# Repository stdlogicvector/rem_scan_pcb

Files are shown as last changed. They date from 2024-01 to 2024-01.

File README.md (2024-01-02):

# rem_scan_pcb

## An open source scan controller for SEMs

- Firmware: https://github.com/stdlogicvector/rem_scan
- GUI: https://github.com/stdlogicvector/rem_scan_gui

This PCB features two 16bit DACs to steer the electron beam of an SEM and two 16bit ADCs to acquire the image signal from up to two detectors.

It can be controlled via USB. The FTDI chip provides a virtual comport, a fast FIFO connection and a JTAG port for flashing the gateware.
Currently, only the serial port is supported in the gateware and the GUI.

Additionally, a VGA monitor can be connected for a live view of the image.
On PCBv1, only the internal blockram is used. This limits the resolution to 100x75 pixels. The image is upscaled to 800x600.

PCBv2 has external RAM and allows a native resolution of 800x600.

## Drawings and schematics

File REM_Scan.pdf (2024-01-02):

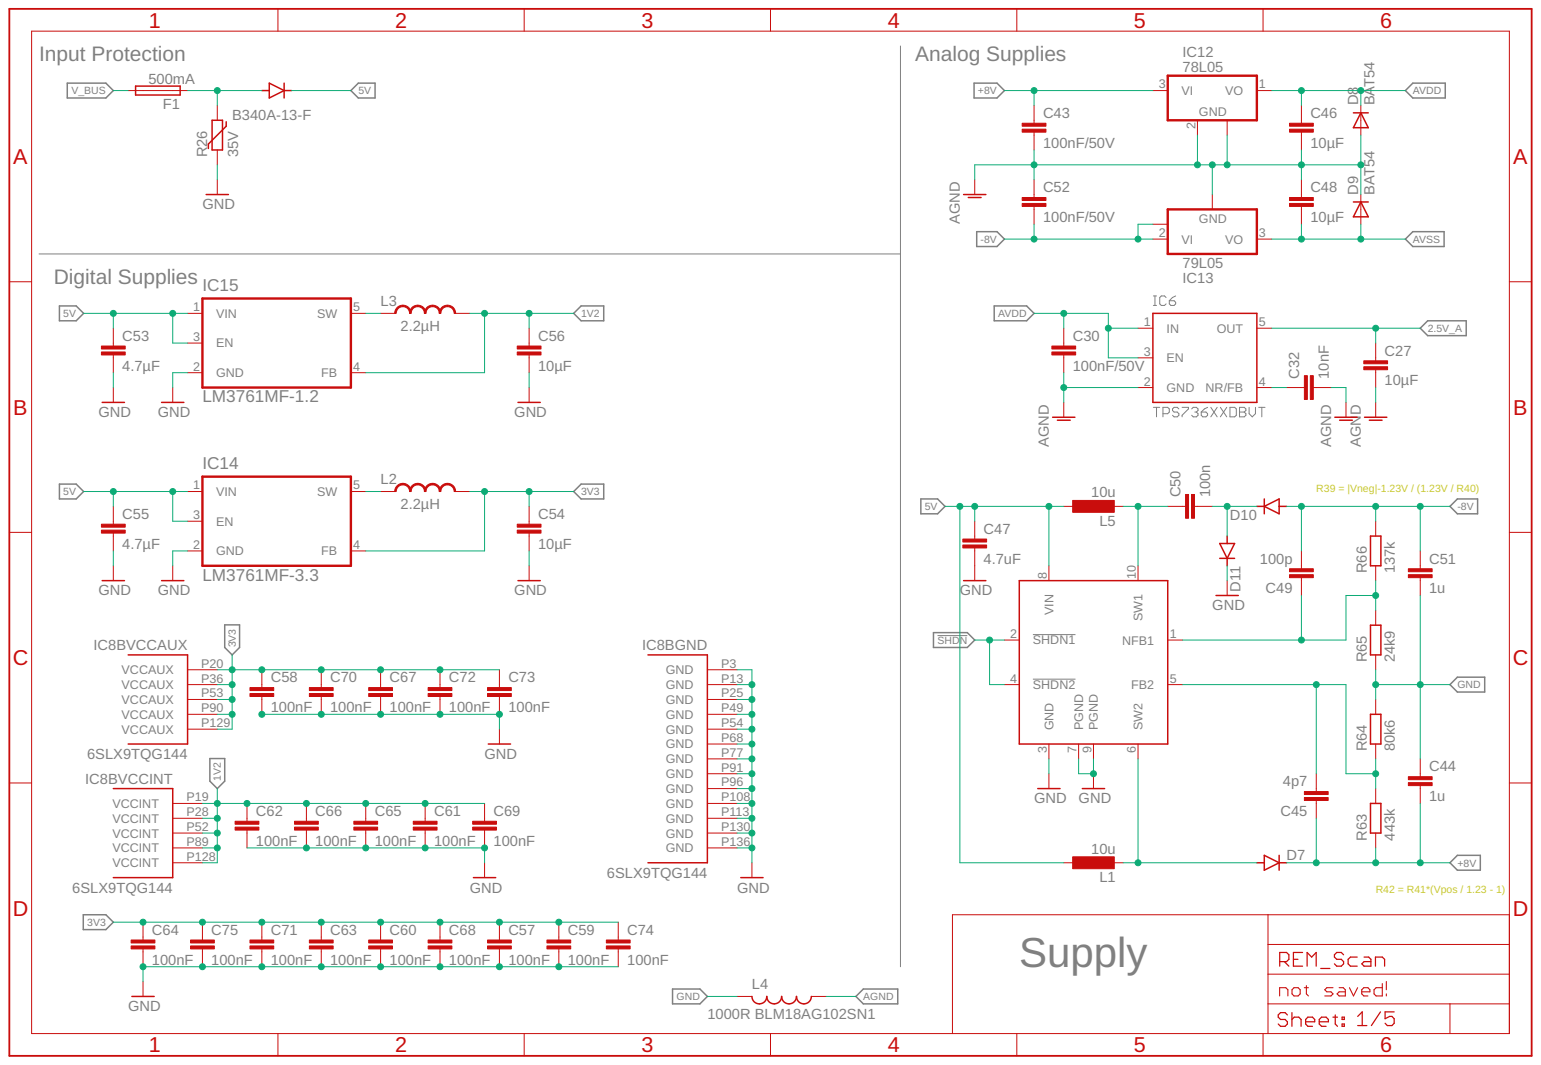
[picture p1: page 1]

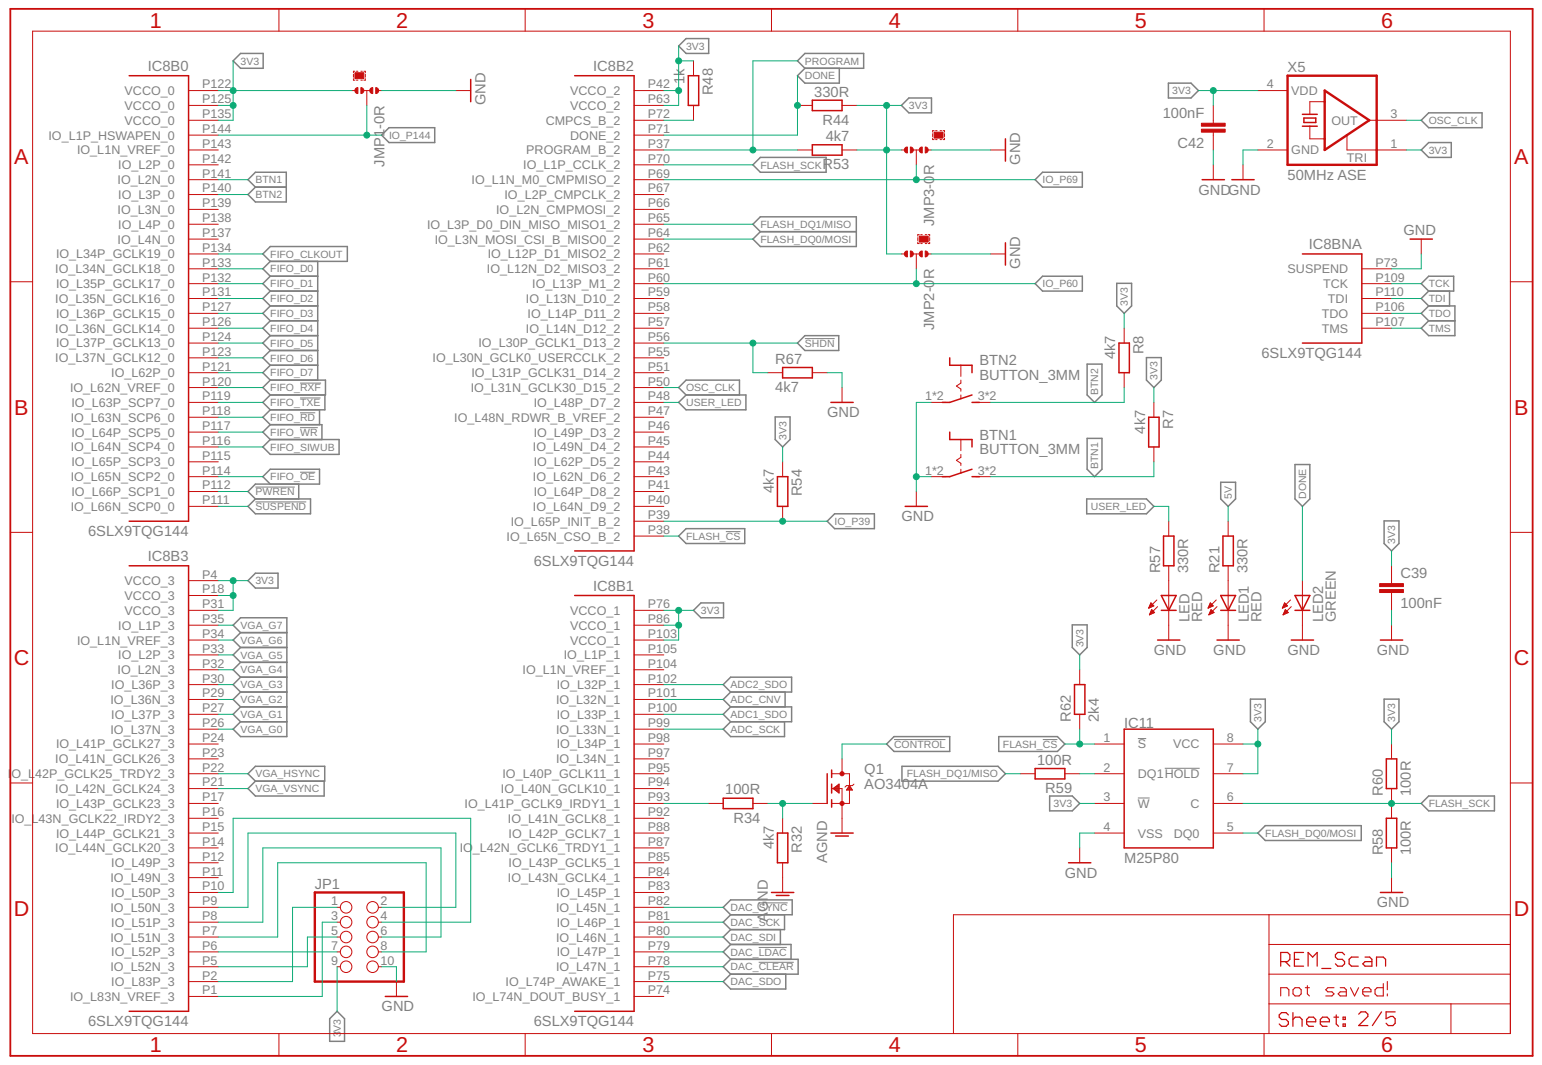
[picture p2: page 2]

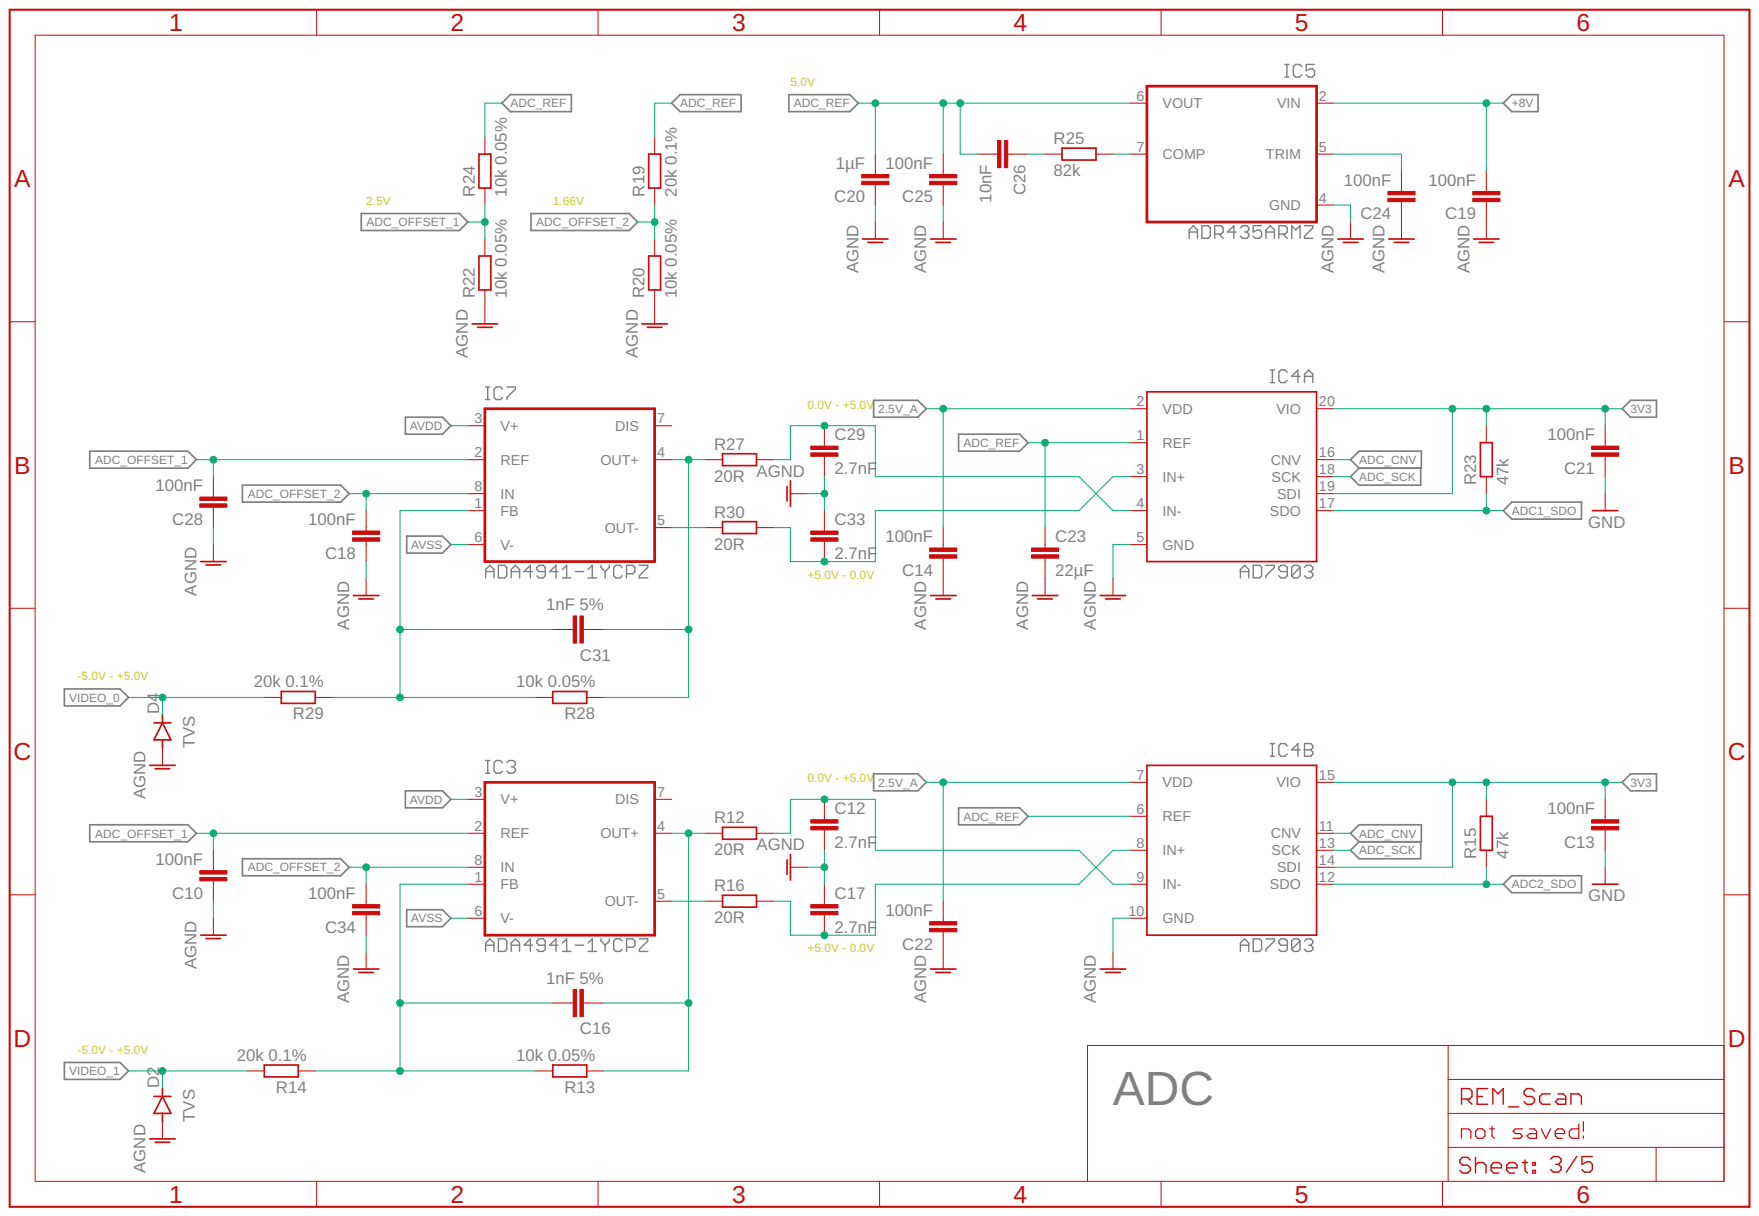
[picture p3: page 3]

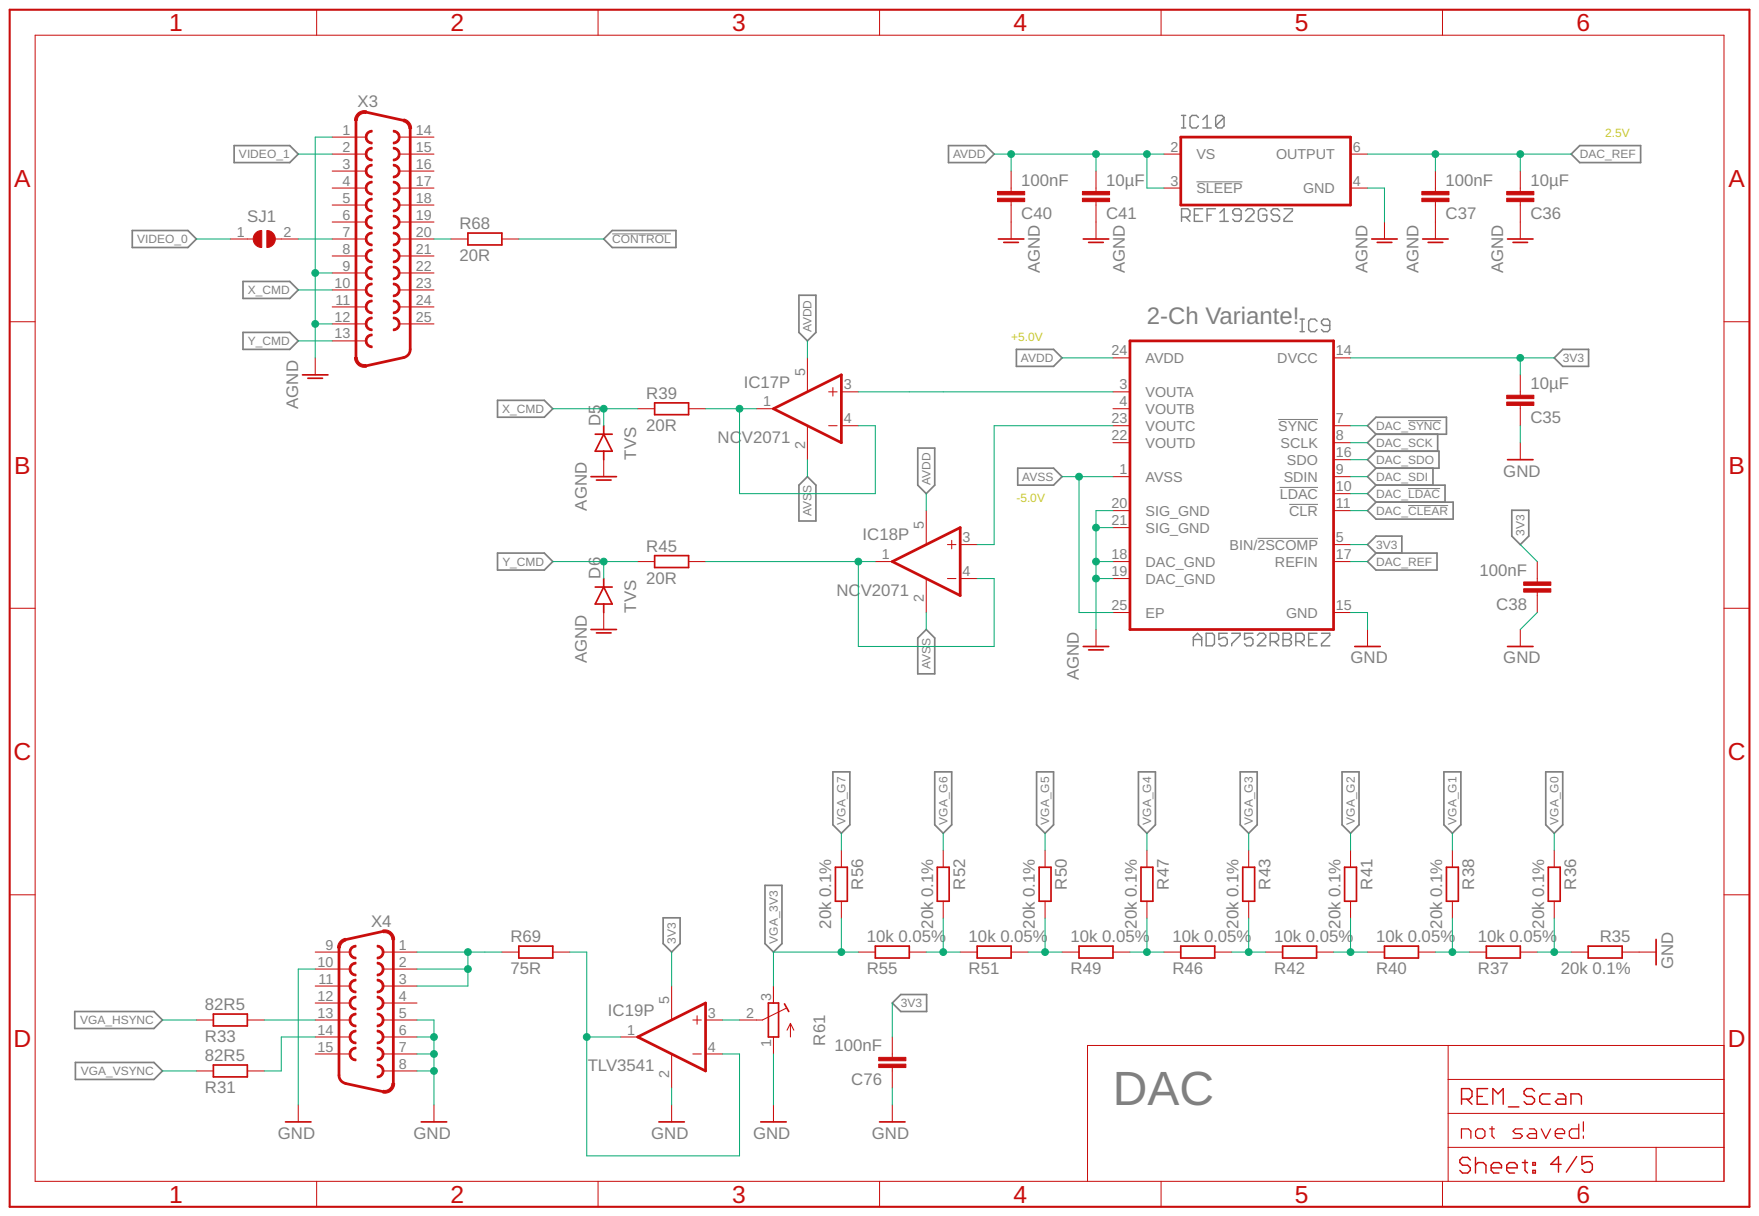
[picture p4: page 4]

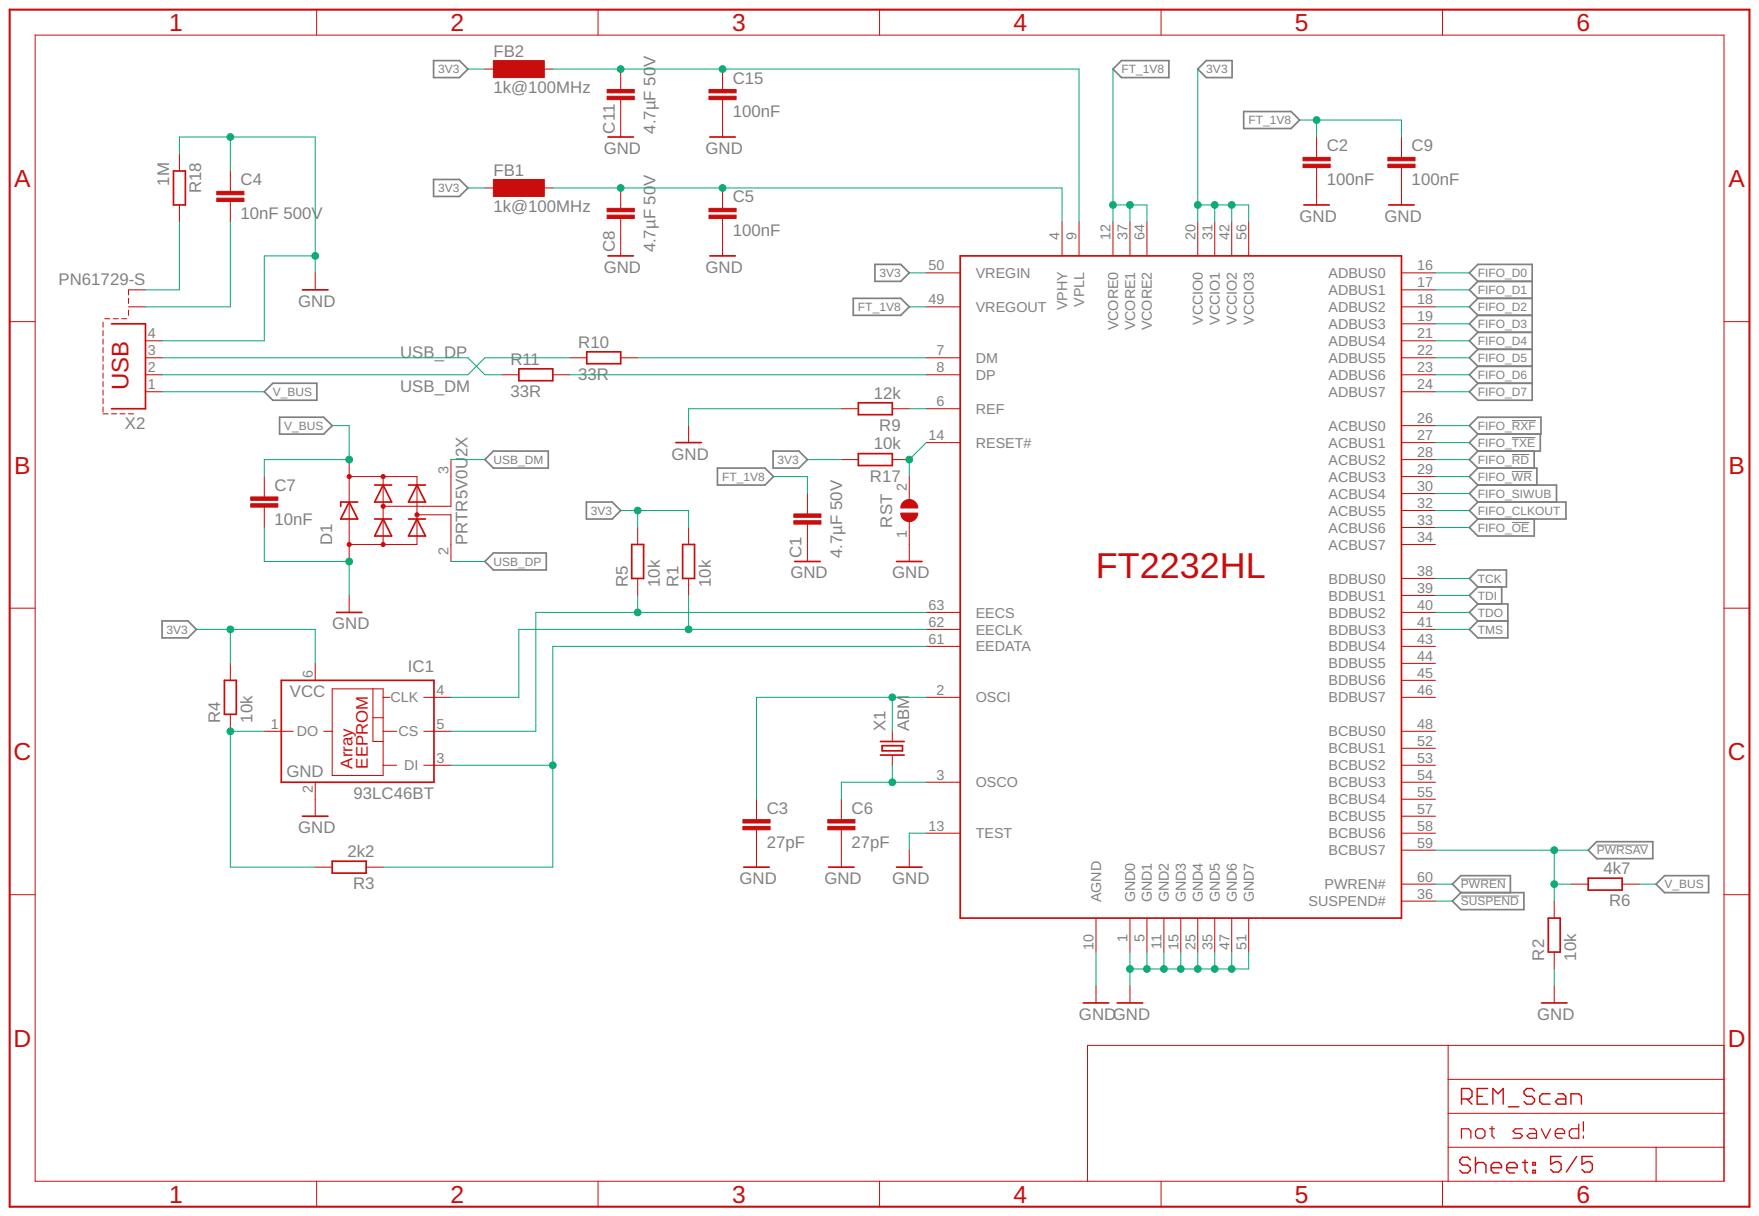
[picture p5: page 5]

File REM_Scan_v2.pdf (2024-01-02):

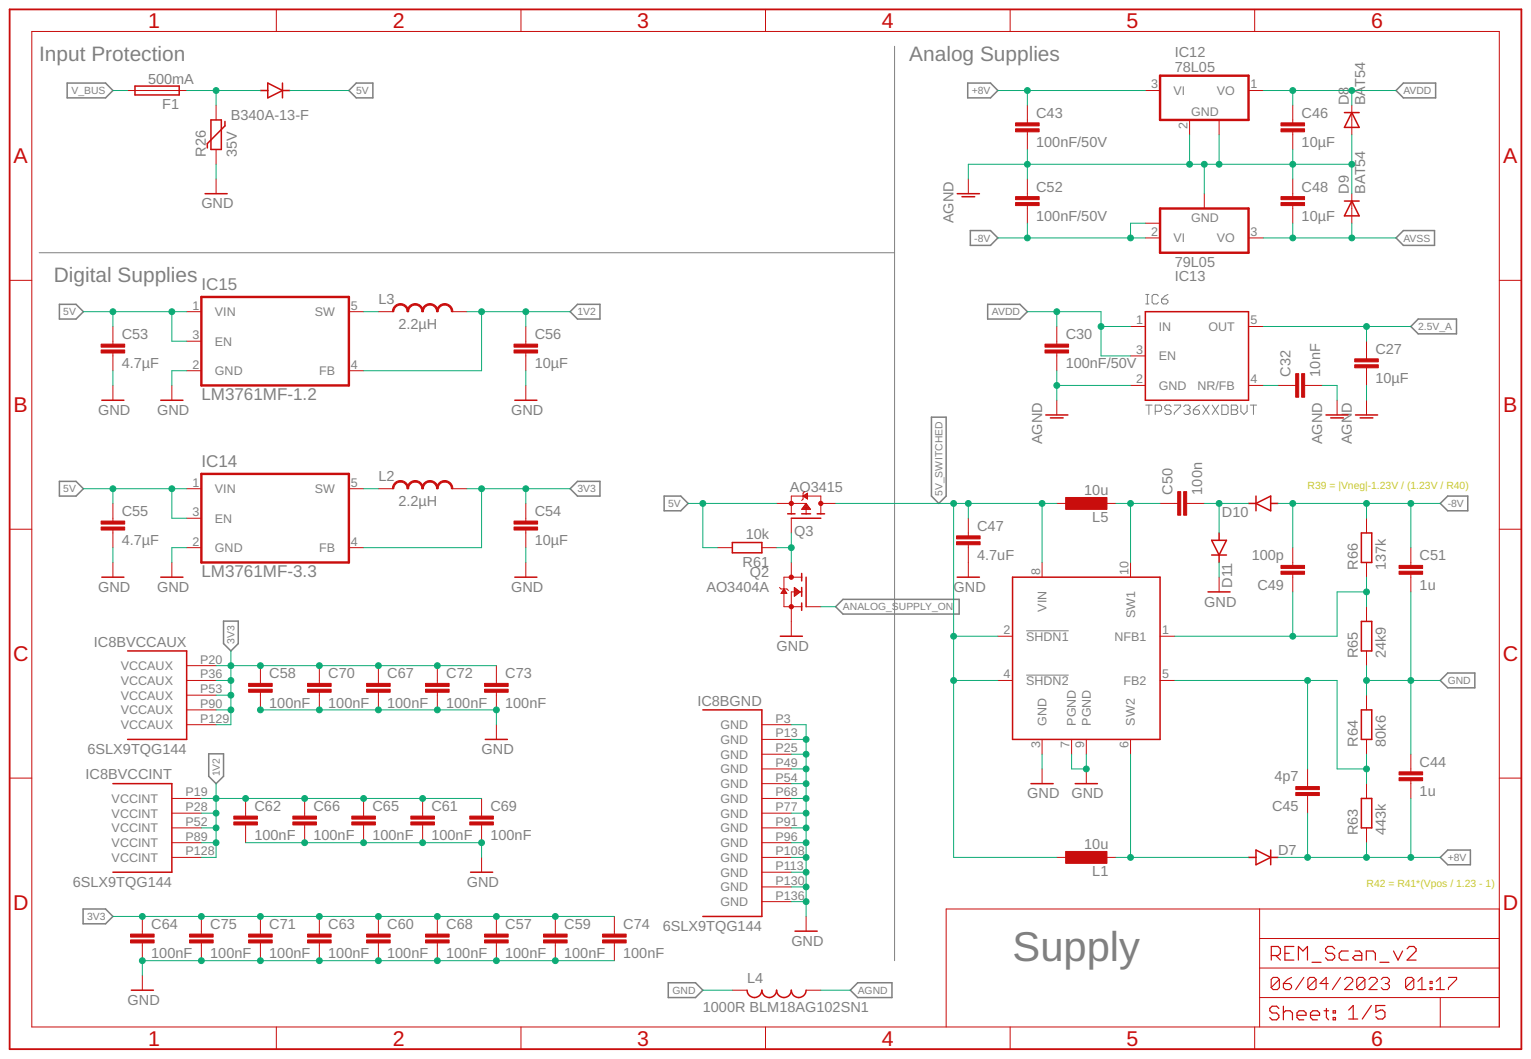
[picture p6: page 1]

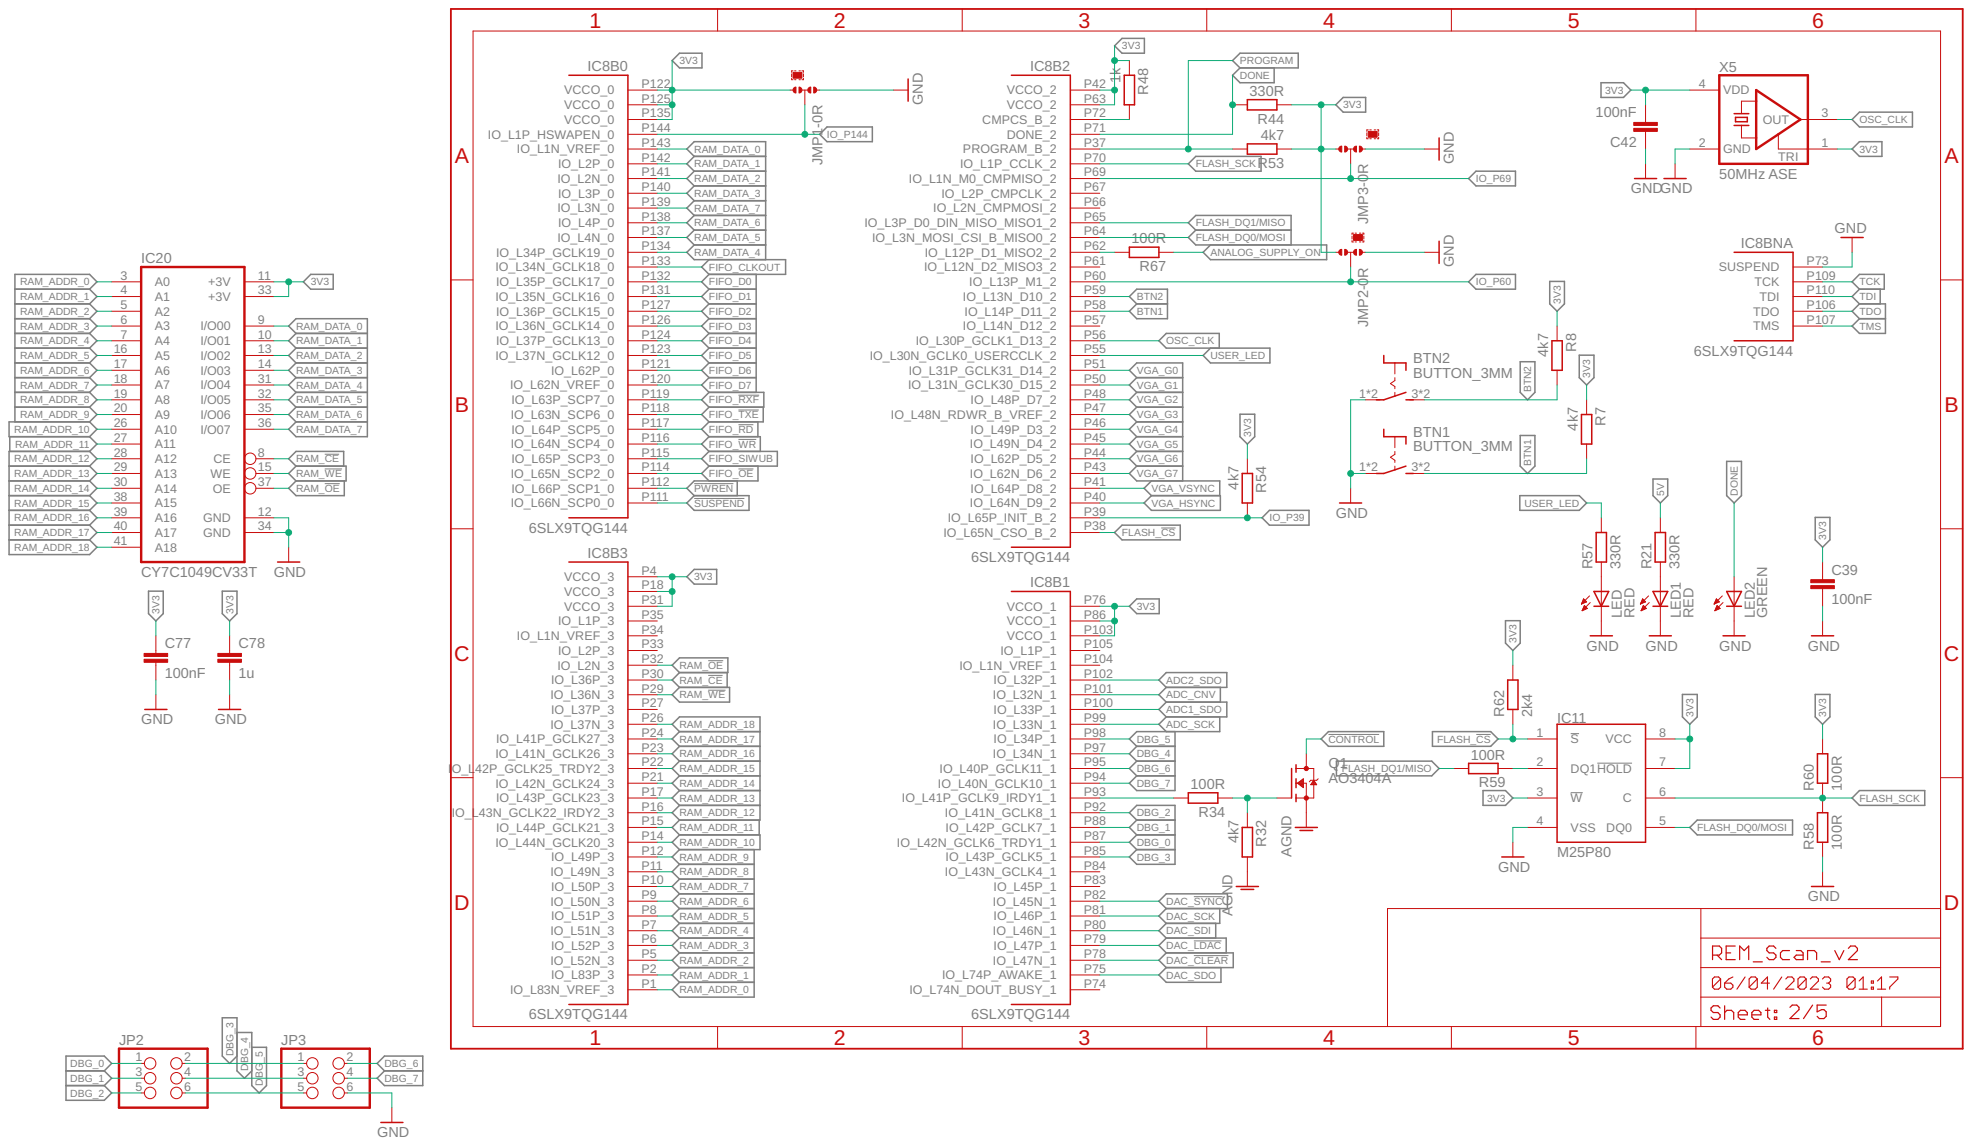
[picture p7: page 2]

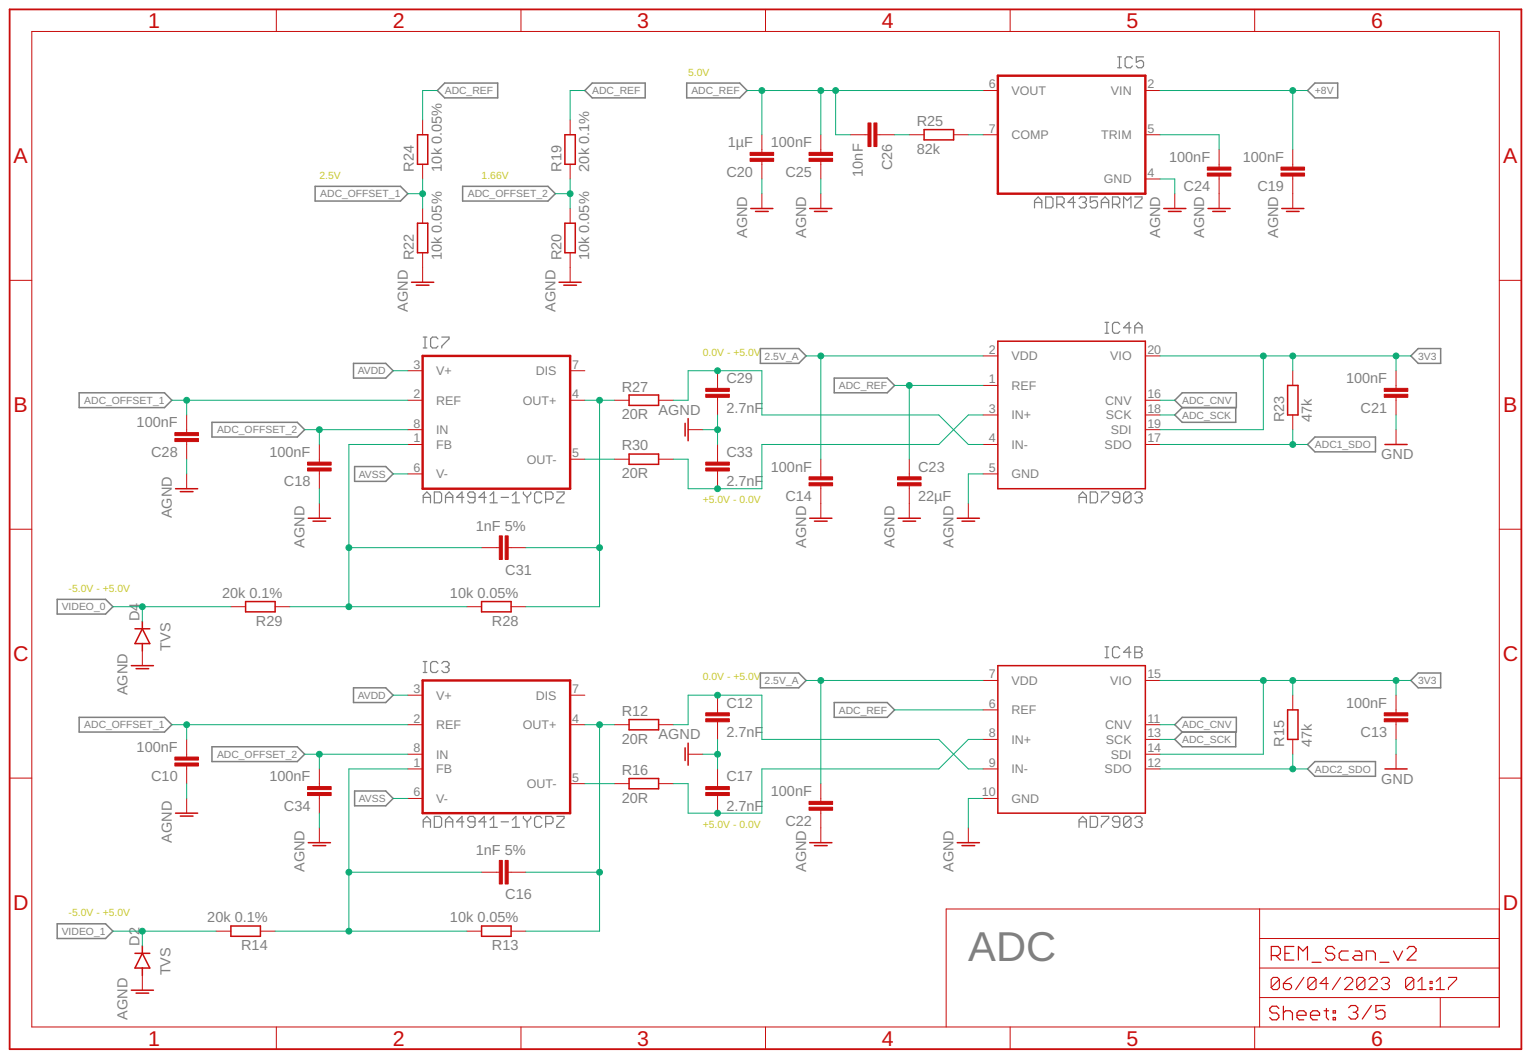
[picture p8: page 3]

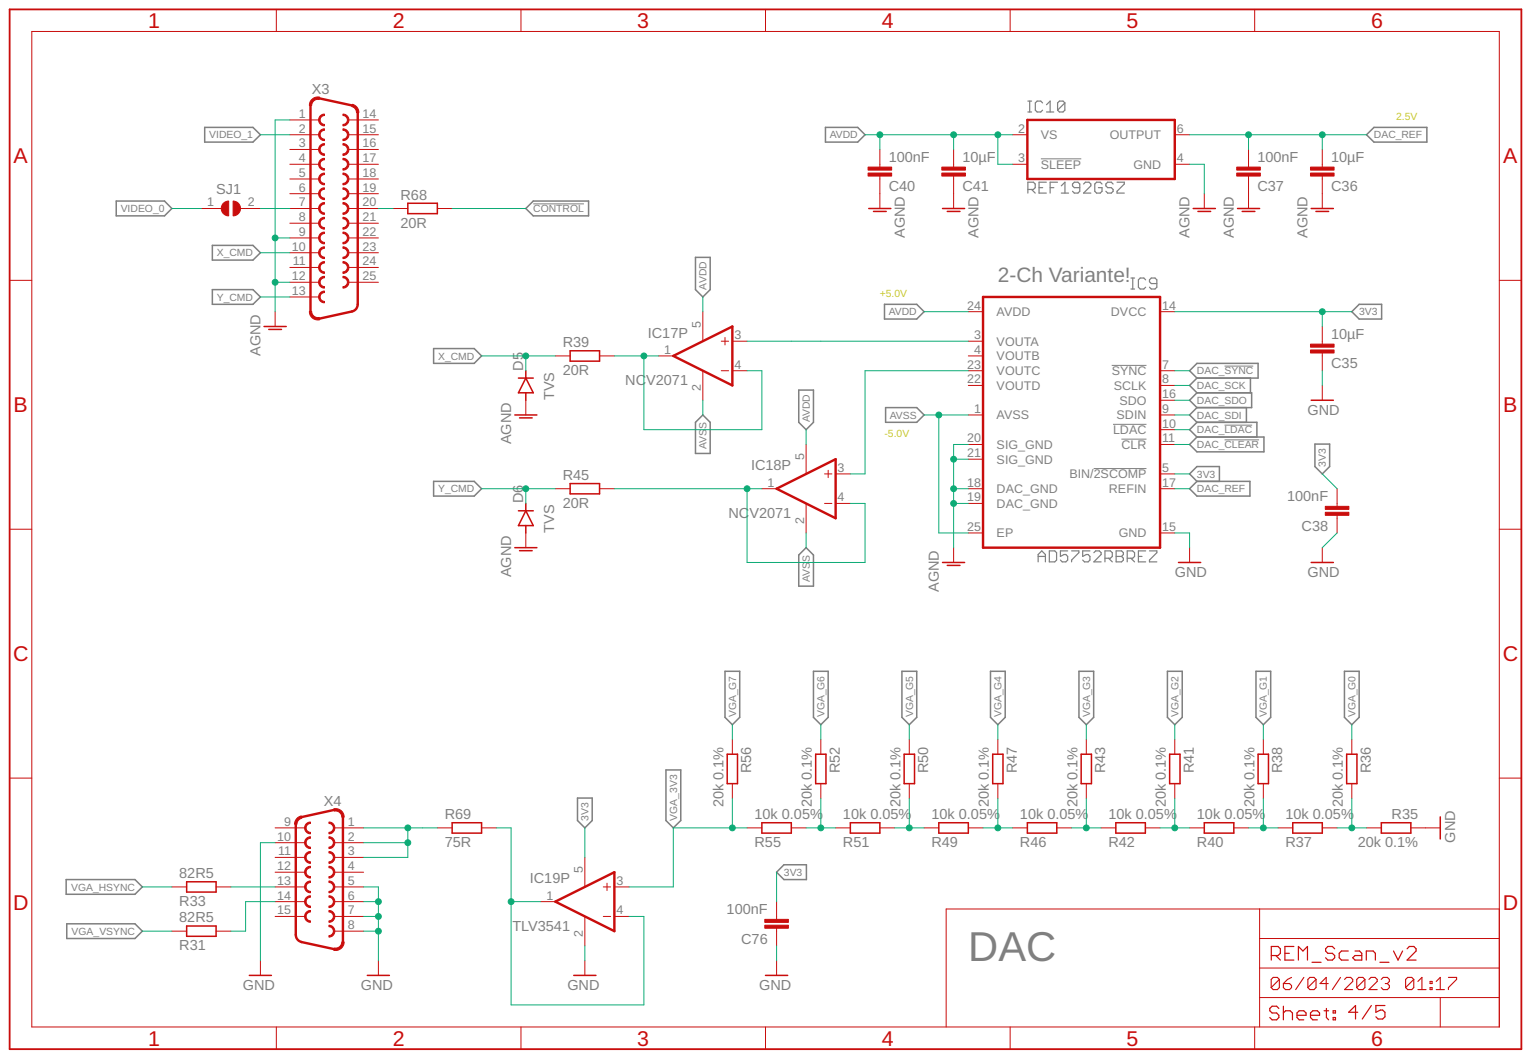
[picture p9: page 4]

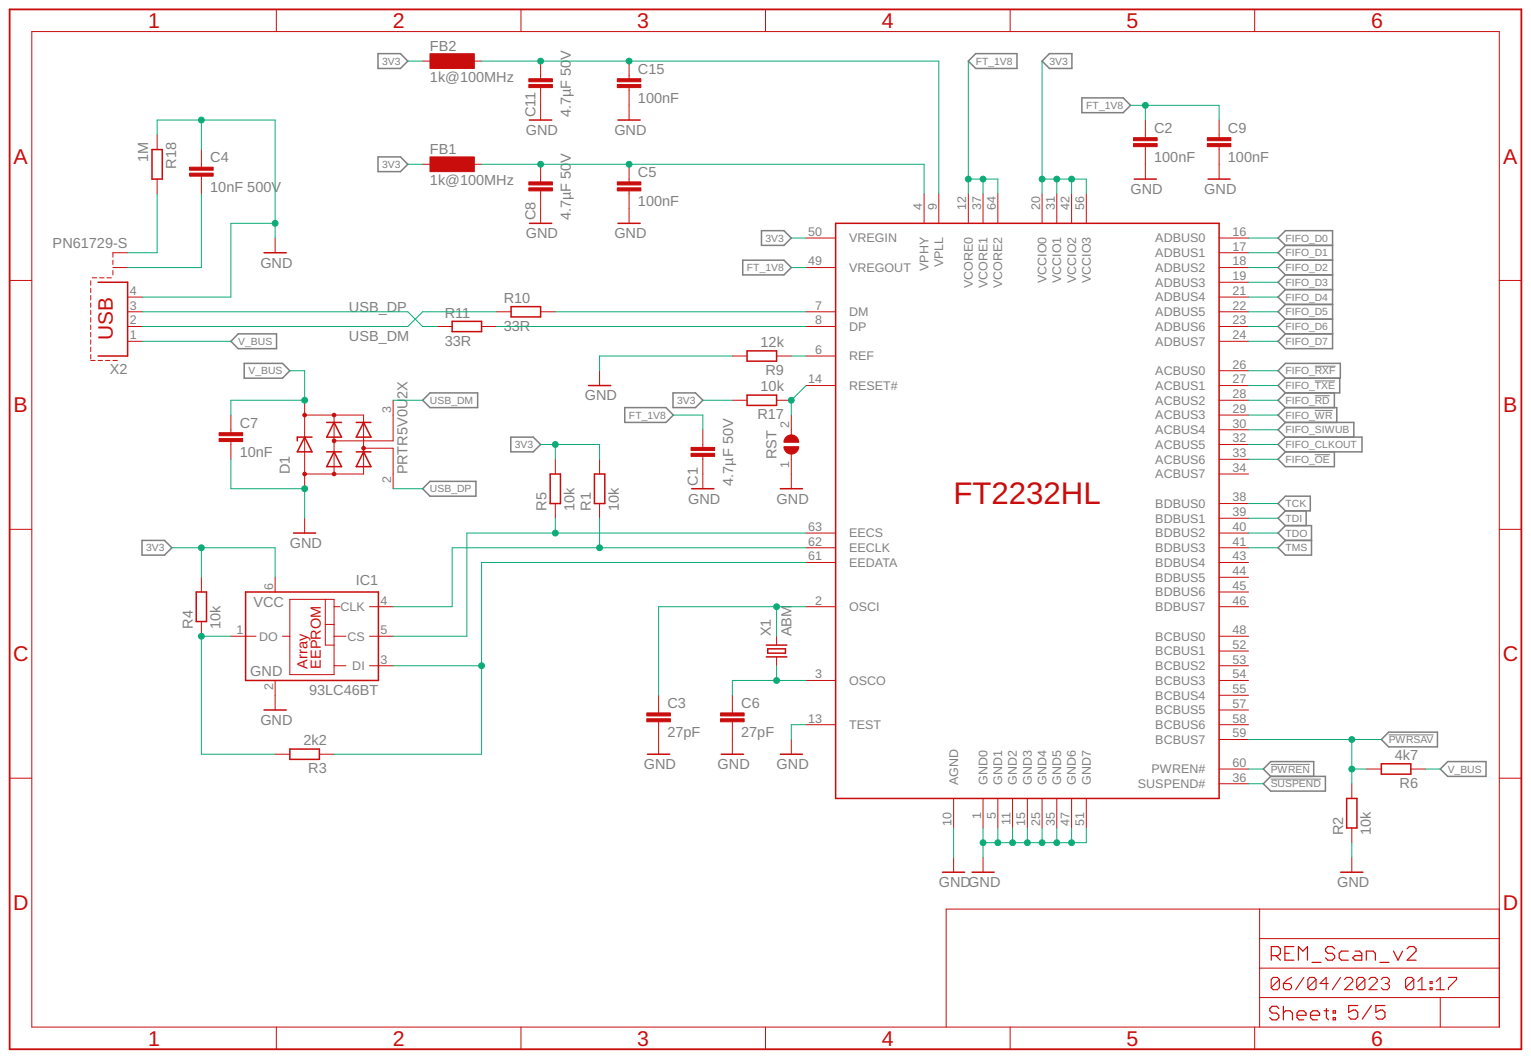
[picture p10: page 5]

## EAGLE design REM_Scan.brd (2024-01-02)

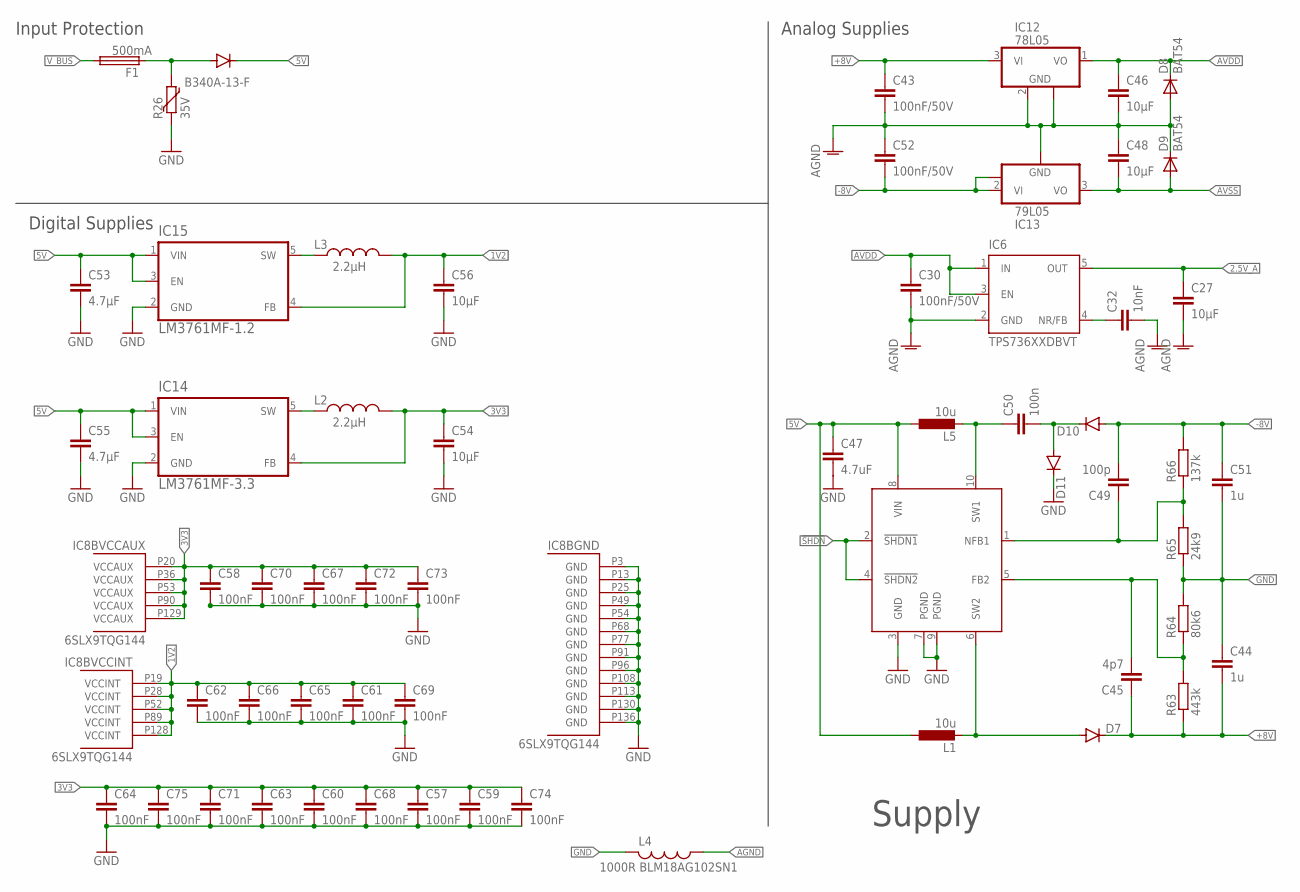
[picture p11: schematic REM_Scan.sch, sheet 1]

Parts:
C27, C46, C48: 10µF; C0603; FARNELL 2497051
C30, C43, C52: 100nF/50V; C0603
C32: 10nF; C0603
C44, C51: 1u; C1206; DIGIKEY 587-5596-1-ND
C45: 4p7; C0603
C47: 4.7uF; C3225
C49: 100p; C0603
C50: 100n; C0603
C53, C55: 4.7µF; C0603
C54, C56: 10µF; C0603
C57, C58, C59, C60, C61, C62, C63, C64, C65, C66, C67, C68, C69, C70, C71, C72, C73, C74, C75: 100nF; C0603
D3: B340A-13-F; DO214AA; FARNELL 1843668
D7, D10, D11: DIODE-SOD323-W; SOD323-W; DIGIKEY 1514-CMDSH05-4TRPBFREECT-ND
D8, D9: BAT54; SOD323-W; FARNELL 1459033
F1: 500mA; 1812; DIGIKEY F8132CT-ND
IC6: TPS736XXDBVT; SOT23-DBV
IC8: 6SLX9TQG144; TQ144; DIGIKEY 122-1747-ND
IC12: 78L05; SOT89; FARNELL 1366573
IC13: 79L05; SOT89; FARNELL 1467770
IC14: LM3761MF-3.3; SOT95P284X122-5N; FARNELL 1685767
IC15: LM3761MF-1.2; SOT95P284X122-5N; FARNELL 1685653
IC16: LT1945; MSOP10; DIGIKEY 505-LT1945EMS#PBF-ND
L1, L5: 10u; L3225P; DIGIKEY 445-174925-1-ND
L2, L3: 2.2µH; SO3314; FARNELL 2457514
L4: 1000R BLM18AG102SN1; L2012C; FARNELL 1515671
R26: 35V; R1206; DIGIKEY 118-ZV25K1206201NIR1CT-ND
R63: 443k; R0603
R64: 80k6; R0603
R65: 24k9; R0603
R66: 137k; R0603

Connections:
1V2: C56.1, C61.1, C62.1, C65.1, C66.1, C69.1, IC8.P19 (VCCINT), IC8.P28 (VCCINT), IC8.P52 (VCCINT), IC8.P89 (VCCINT), IC8.P128 (VCCINT), IC15.4 (FB), L3.2
2.5V_A: C27.1, IC6.5 (OUT); also elsewhere on the board
3V3: C54.1, C57.1, C58.1, C59.1, C60.1, C63.1, C64.1, C67.1, C68.1, C70.1, C71.1, C72.1, C73.1, C74.1, C75.1, IC8.P20 (VCCAUX), IC8.P36 (VCCAUX), IC8.P53 (VCCAUX), IC8.P90 (VCCAUX), IC8.P129 (VCCAUX), IC14.4 (FB), L2.2; also elsewhere on the board
5V: C47.1, C53.1, C55.1, D3.C, IC14.1 (VIN), IC14.3 (EN), IC15.1 (VIN), IC15.3 (EN), IC16.8 (VIN), L1.1, L5.1; also elsewhere on the board
!SHDN: IC16.2 (!SHDN1), IC16.4 (!SHDN2); also elsewhere on the board
+8V: C43.1, C44.2, C45.1, D7.C, IC12.3 (VI), R63.1; also elsewhere on the board
-8V: C49.2, C51.1, C52.2, D10.A, IC13.2 (VI), IC13.2@1 (VIN), R66.2
AGND: C27.2, C30.2, C32.2, C43.2, C46.2, C48.1, C52.1, D8.A, D9.C, IC6.2 (GND), IC12.2 (GND), IC12.2@1 (GND), IC13.1 (GND), L4.1; also elsewhere on the board
AVDD: C30.1, C46.1, D8.C, IC6.1 (IN), IC6.3 (EN), IC12.1 (VO); also elsewhere on the board
AVSS: C48.2, D9.A, IC13.3 (VO); also elsewhere on the board
GND: C44.1, C47.2, C51.2, C53.2, C54.2, C55.2, C56.2, C57.2, C58.2, C59.2, C60.2, C61.2, C62.2, C63.2, C64.2, C65.2, C66.2, C67.2, C68.2, C69.2, C70.2, C71.2, C72.2, C73.2, C74.2, C75.2, D11.C, IC8.P3 (GND), IC8.P13 (GND), IC8.P25 (GND), IC8.P49 (GND), IC8.P54 (GND), IC8.P68 (GND), IC8.P77 (GND), IC8.P91 (GND), IC8.P96 (GND), IC8.P108 (GND), IC8.P113 (GND), IC8.P130 (GND), IC8.P136 (GND), IC14.2 (GND), IC15.2 (GND), IC16.3 (GND), IC16.7 (PGND), IC16.9 (PGND), L4.2, R26.1, R64.2, R65.1; also elsewhere on the board
unnamed: IC15.5 (SW), L3.1
unnamed: C32.1, IC6.4 (NR/FB)
unnamed: C50.1, IC16.10 (SW1), L5.2
unnamed: C50.2, D10.C, D11.A
unnamed: D7.A, IC16.6 (SW2), L1.2
unnamed: C49.1, IC16.1 (NFB1), R65.2, R66.1
unnamed: C45.2, IC16.5 (FB2), R63.2, R64.1
unnamed: IC14.5 (SW), L2.1
SUPPLY_SEC: D3.A, F1.1, R26.2
V_BUS: F1.2; also elsewhere on the board

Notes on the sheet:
Input Protection
Supply
Digital Supplies
Analog Supplies

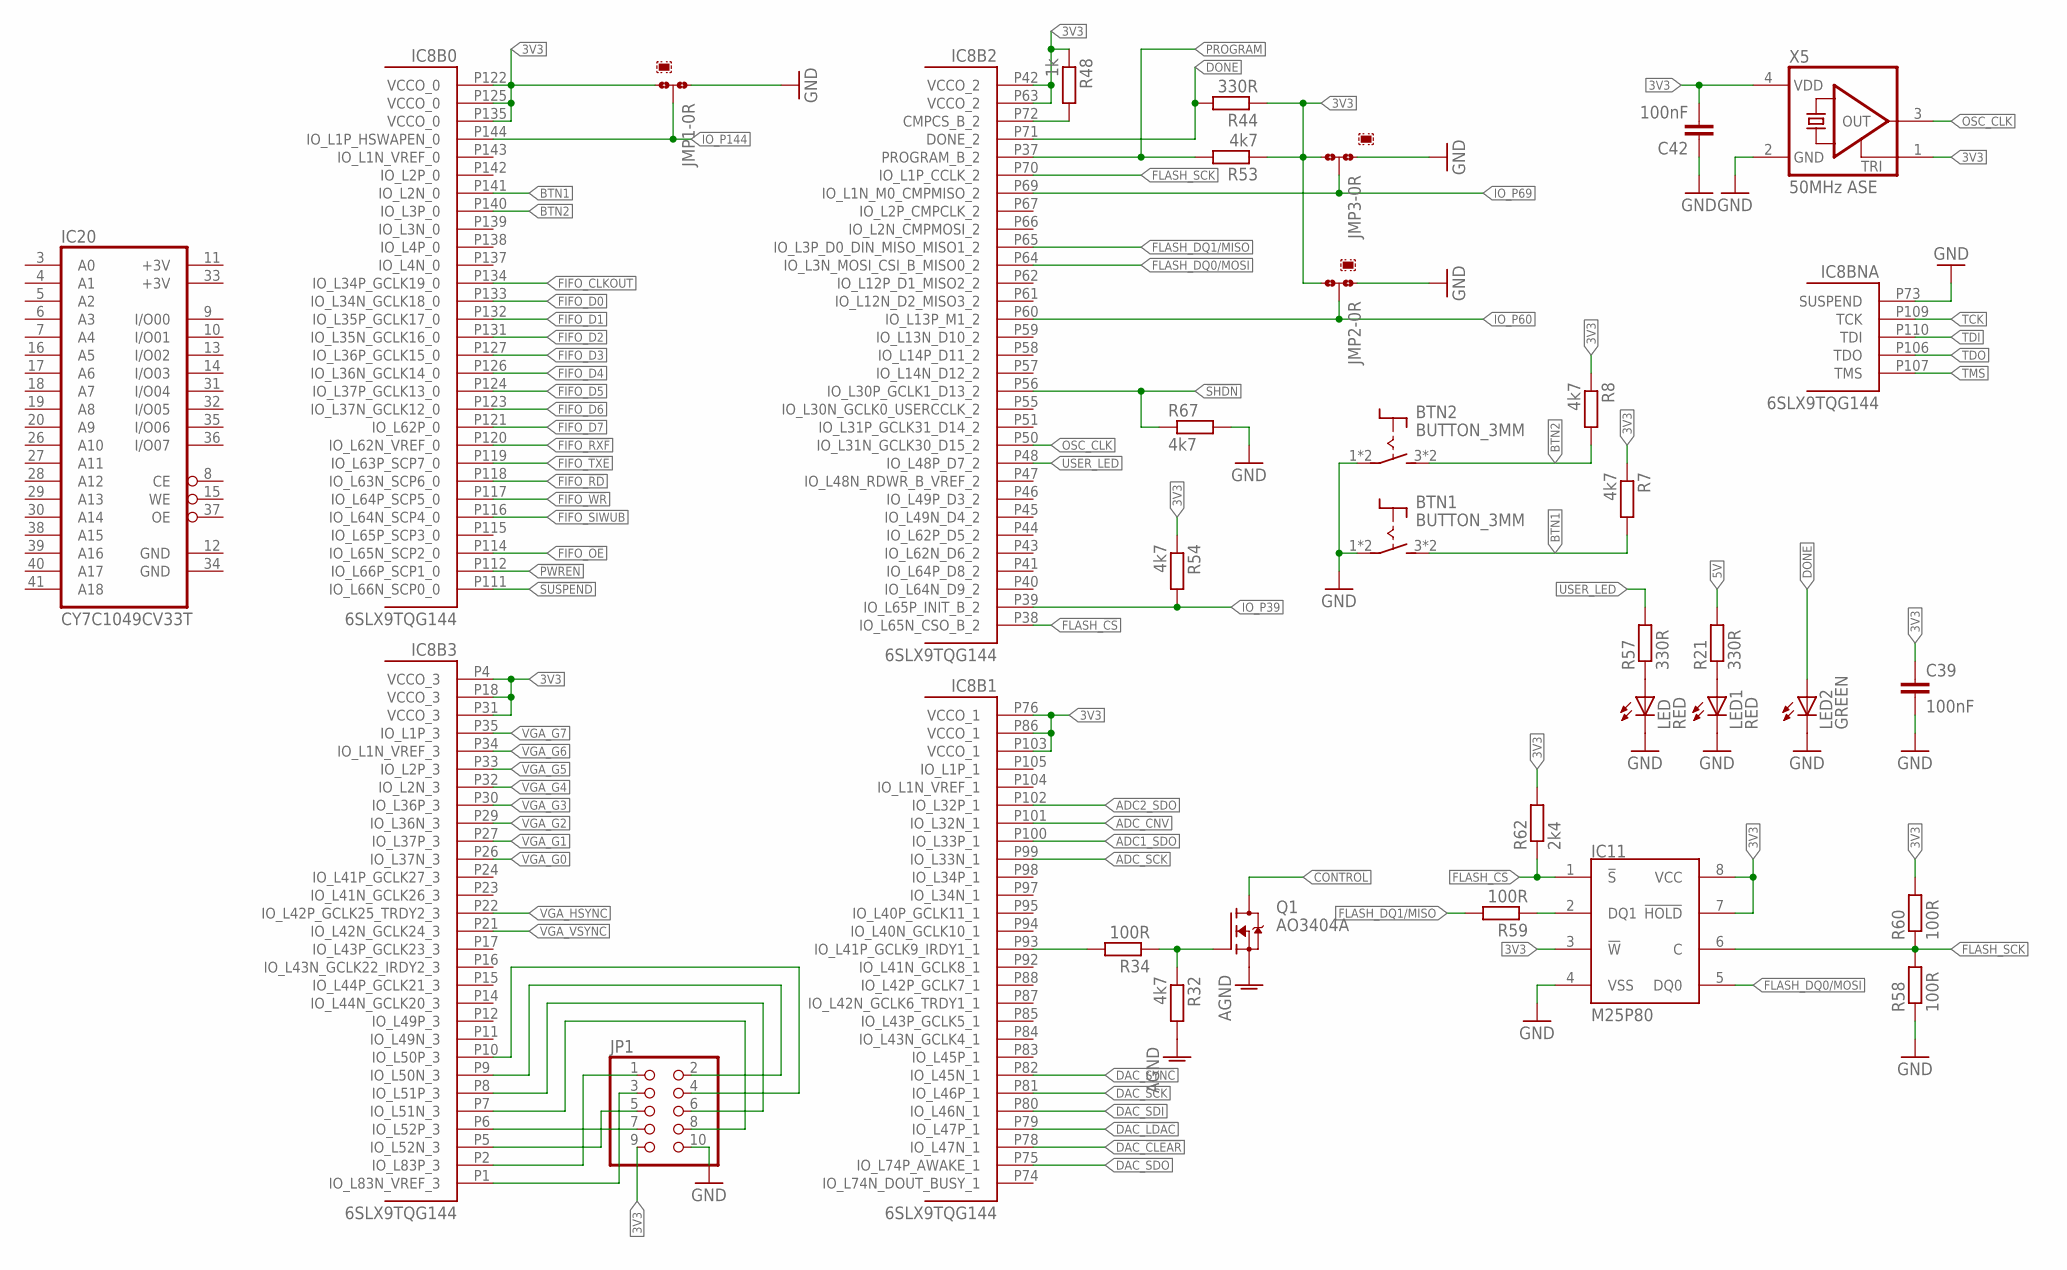
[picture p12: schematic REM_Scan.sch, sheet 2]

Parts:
BTN1, BTN2: BUTTON_3MM
C39, C42: 100nF; C0603
IC8: 6SLX9TQG144; TQ144; DIGIKEY 122-1747-ND
IC11: M25P80; SO-08
IC20: CY7C1049CV33T; TSOPII-Z44
JMP1, JMP2, JMP3: 1k; A0R-JMP
JP1: PINHD-2X5; 2X05
LED, LED1: RED; CHIP-LED0603; FARNELL 1685068
LED2: GREEN; CHIP-LED0603; FARNELL 1685068
Q1: AO3404A; SOT23; LCSC C30010
R7, R8, R32, R53, R54, R67: 4k7; R0603
R21, R44, R57: 330R; R0603
R34, R58, R59, R60: 100R; R0603
R48: 1k; R0603
R62: 2k4; R0603
X5: 50MHz ASE; ASE; DIGIKEY 535-9577-1-ND

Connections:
3V3: C39.1, C42.2, IC8.P4 (VCCO_3), IC8.P18 (VCCO_3), IC8.P31 (VCCO_3), IC8.P42 (VCCO_2), IC8.P63 (VCCO_2), IC8.P76 (VCCO_1), IC8.P86 (VCCO_1), IC8.P103 (VCCO_1), IC8.P122 (VCCO_0), IC8.P125 (VCCO_0), IC8.P135 (VCCO_0), IC11.3 (!W), IC11.7 (!HOLD), IC11.8 (VCC), JMP1.3, JMP2.3, JMP3.3, JP1.9, R7.1, R8.1, R44.1, R48.1, R53.1, R54.1, R60.2, R62.2, X5.1 (TRI), X5.4 (VDD); also elsewhere on the board
5V: R21.2; also elsewhere on the board
!CONTROL: Q1.3 (D); also elsewhere on the board
!PWREN: IC8.P112 (IO_L66P_SCP1_0); also elsewhere on the board
!SHDN: IC8.P56 (IO_L30P_GCLK1_D13_2), R67.1; also elsewhere on the board
!SUSPEND: IC8.P111 (IO_L66N_SCP0_0); also elsewhere on the board
+3V: IC20.11 (+3V), IC20.33 (+3V)
ADC1_SDO: IC8.P100 (IO_L33P_1); also elsewhere on the board
ADC2_SDO: IC8.P102 (IO_L32P_1); also elsewhere on the board
ADC_CNV: IC8.P101 (IO_L32N_1); also elsewhere on the board
ADC_SCK: IC8.P99 (IO_L33N_1); also elsewhere on the board
AGND: Q1.2 (S), R32.2; also elsewhere on the board
BTN1: BTN1.3 (S), BTN1.4 (S), IC8.P141 (IO_L2N_0), R7.2
BTN2: BTN2.3 (S), BTN2.4 (S), IC8.P140 (IO_L3P_0), R8.2
DAC_!CLEAR: IC8.P78 (IO_L47N_1); also elsewhere on the board
DAC_!LDAC: IC8.P79 (IO_L47P_1); also elsewhere on the board
DAC_!SYNC: IC8.P82 (IO_L45N_1); also elsewhere on the board
DAC_SCK: IC8.P81 (IO_L46P_1); also elsewhere on the board
DAC_SDI: IC8.P80 (IO_L46N_1); also elsewhere on the board
DAC_SDO: IC8.P75 (IO_L74P_AWAKE_1); also elsewhere on the board
DONE: IC8.P71 (DONE_2), LED2.A, R44.2
FIFO_!OE: IC8.P114 (IO_L65N_SCP2_0); also elsewhere on the board
FIFO_!RD: IC8.P118 (IO_L63N_SCP6_0); also elsewhere on the board
FIFO_!RXF: IC8.P120 (IO_L62N_VREF_0); also elsewhere on the board
FIFO_!TXE: IC8.P119 (IO_L63P_SCP7_0); also elsewhere on the board
FIFO_!WR: IC8.P117 (IO_L64P_SCP5_0); also elsewhere on the board
FIFO_CLKOUT: IC8.P134 (IO_L34P_GCLK19_0); also elsewhere on the board
FIFO_D0: IC8.P133 (IO_L34N_GCLK18_0); also elsewhere on the board
FIFO_D1: IC8.P132 (IO_L35P_GCLK17_0); also elsewhere on the board
FIFO_D2: IC8.P131 (IO_L35N_GCLK16_0); also elsewhere on the board
FIFO_D3: IC8.P127 (IO_L36P_GCLK15_0); also elsewhere on the board
FIFO_D4: IC8.P126 (IO_L36N_GCLK14_0); also elsewhere on the board
FIFO_D5: IC8.P124 (IO_L37P_GCLK13_0); also elsewhere on the board
FIFO_D6: IC8.P123 (IO_L37N_GCLK12_0); also elsewhere on the board
FIFO_D7: IC8.P121 (IO_L62P_0); also elsewhere on the board
FIFO_SIWUB: IC8.P116 (IO_L64N_SCP4_0); also elsewhere on the board
FLASH_!CS: IC8.P38 (IO_L65N_CSO_B_2), IC11.1 (!S), R62.1
FLASH_DQ0/MOSI: IC8.P64 (IO_L3N_MOSI_CSI_B_MISO0_2), IC11.5 (DQ0)
FLASH_DQ1/MISO: IC8.P65 (IO_L3P_D0_DIN_MISO_MISO1_2), R59.2
FLASH_SCK: IC8.P70 (IO_L1P_CCLK_2), IC11.6 (C), R58.2, R60.1
GND: BTN1.1, BTN1.2, BTN2.1, BTN2.2, C39.2, C42.1, IC8.P73 (SUSPEND), IC11.4 (VSS), IC20.12 (GND), IC20.34 (GND), JMP1.1, JMP2.1, JMP3.1, JP1.10, LED.C, LED1.C, LED2.C, R58.1, R67.2, X5.2 (GND); also elsewhere on the board
IO_P39: IC8.P39 (IO_L65P_INIT_B_2), R54.2
IO_P60: IC8.P60 (IO_L13P_M1_2), JMP2.2
IO_P69: IC8.P69 (IO_L1N_M0_CMPMISO_2), JMP3.2
IO_P144: IC8.P144 (IO_L1P_HSWAPEN_0), JMP1.2
unnamed: IC11.2 (DQ1), R59.1
unnamed: LED1.A, R21.1
unnamed: Q1.1 (G), R32.1, R34.1
unnamed: IC8.P72 (CMPCS_B_2), R48.2
unnamed: IC8.P93 (IO_L41P_GCLK9_IRDY1_1), R34.2
unnamed: LED.A, R57.1
unnamed: IC8.P6 (IO_L52P_3), JP1.7
unnamed: IC8.P7 (IO_L51N_3), JP1.8
unnamed: IC8.P5 (IO_L52N_3), JP1.5
unnamed: IC8.P8 (IO_L51P_3), JP1.6
unnamed: IC8.P1 (IO_L83N_VREF_3), JP1.3
unnamed: IC8.P2 (IO_L83P_3), JP1.1
unnamed: IC8.P9 (IO_L50N_3), JP1.2
unnamed: IC8.P10 (IO_L50P_3), JP1.4
OSC_CLK: IC8.P50 (IO_L31N_GCLK30_D15_2), X5.3 (OUT)
PROGRAM: IC8.P37 (PROGRAM_B_2), R53.2
TCK: IC8.P109 (TCK); also elsewhere on the board
TDI: IC8.P110 (TDI); also elsewhere on the board
TDO: IC8.P106 (TDO); also elsewhere on the board
TMS: IC8.P107 (TMS); also elsewhere on the board
USER_LED: IC8.P48 (IO_L48P_D7_2), R57.2
VGA_G0: IC8.P26 (IO_L37N_3); also elsewhere on the board
VGA_G1: IC8.P27 (IO_L37P_3); also elsewhere on the board
VGA_G2: IC8.P29 (IO_L36N_3); also elsewhere on the board
VGA_G3: IC8.P30 (IO_L36P_3); also elsewhere on the board
VGA_G4: IC8.P32 (IO_L2N_3); also elsewhere on the board
VGA_G5: IC8.P33 (IO_L2P_3); also elsewhere on the board
VGA_G6: IC8.P34 (IO_L1N_VREF_3); also elsewhere on the board
VGA_G7: IC8.P35 (IO_L1P_3); also elsewhere on the board
VGA_HSYNC: IC8.P22 (IO_L42P_GCLK25_TRDY2_3); also elsewhere on the board
VGA_VSYNC: IC8.P21 (IO_L42N_GCLK24_3); also elsewhere on the board

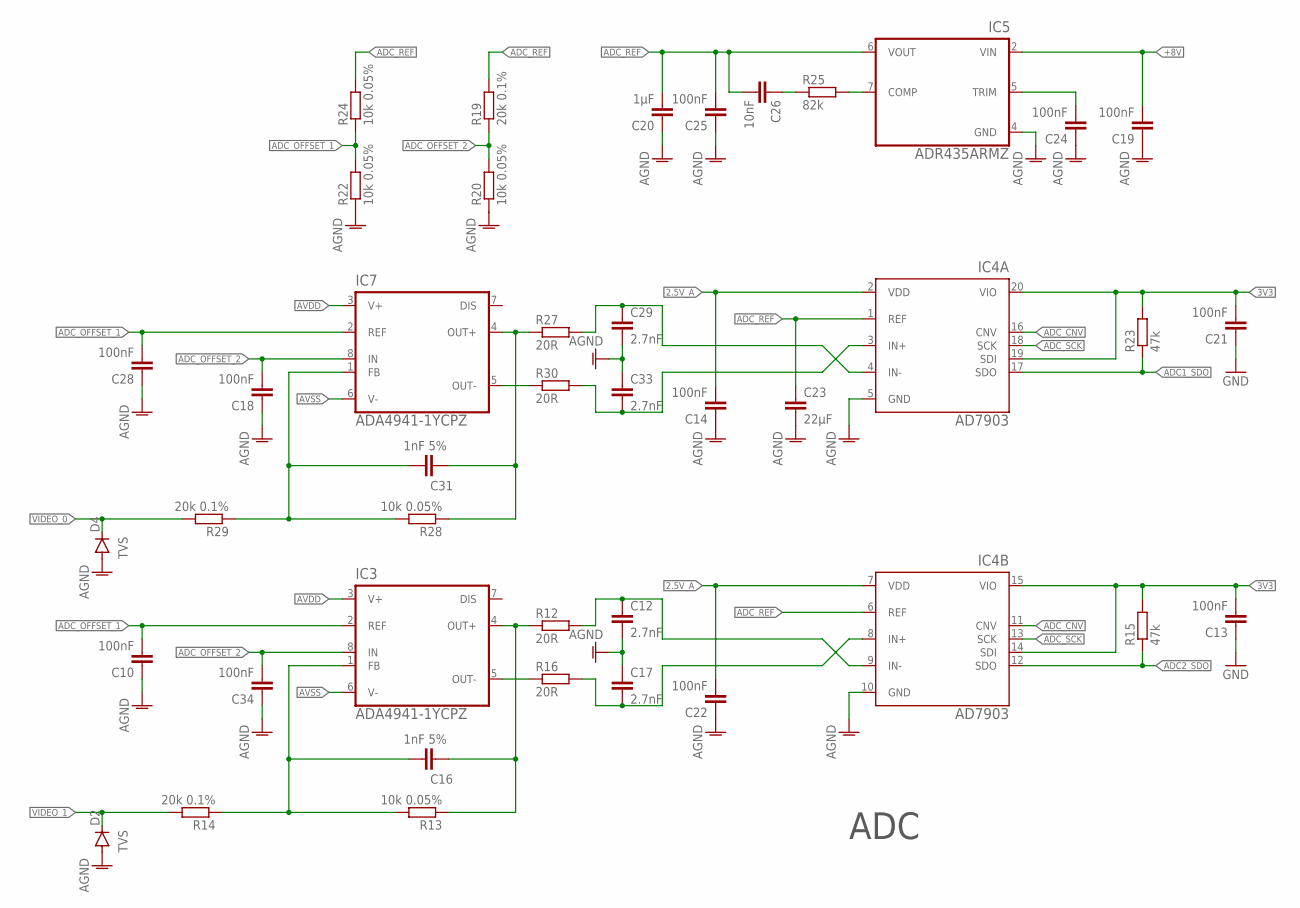
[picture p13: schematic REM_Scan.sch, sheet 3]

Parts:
C10, C13, C14, C18, C19, C21, C22, C24, C25, C28, C34: 100nF; C0603
C12, C17, C29, C33: 2.7nF; C0603K; FARNELL 1759094
C16, C31: 1nF 5%; C0603; FARNELL 1789718
C20: 1µF; C0603; FARNELL 2496835
C23: 22µF; C0805K; FARNELL 1845739
C26: 10nF; C0603
D2, D4: TVS; SOD123; DIGIKEY 641-1986-1-ND
IC3, IC7: ADA4941-1YCPZ; LFCSP_VD8_CP-8-2
IC4: AD7903; RQ-20
IC5: ADR435ARMZ; MSOP08
R12, R16, R27, R30: 20R; R0603; FARNELL 9330763
R13, R20, R22, R24, R28: 10k 0.05%; R0603; FARNELL 1688472
R14, R19, R29: 20k 0.1%; R0603; FARNELL 1717605
R15, R23: 47k; R0603; FARNELL 2141566
R25: 82k; R0603; FARNELL 9331573

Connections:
2.5V_A: C14.2, C22.2, IC4.2 (VDD), IC4.7 (VDD); also elsewhere on the board
3V3: C13.2, C21.2, IC4.14 (SDI), IC4.15 (VIO), IC4.19 (SDI), IC4.20 (VIO), R15.2, R23.2; also elsewhere on the board
+8V: C19.2, IC5.2 (VIN); also elsewhere on the board
ADC1_SDO: IC4.17 (SDO), R23.1; also elsewhere on the board
ADC2_SDO: IC4.12 (SDO), R15.1; also elsewhere on the board
ADC_CNV: IC4.11 (CNV), IC4.16 (CNV); also elsewhere on the board
ADC_OFFSET_1: C10.2, C28.2, IC3.2 (REF), IC7.2 (REF), R22.2, R24.1
ADC_OFFSET_2: C18.2, C34.2, IC3.8 (IN), IC7.8 (IN), R19.1, R20.2
ADC_REF: C20.2, C23.1, C25.2, C26.2, IC4.1 (REF), IC4.6 (REF), IC5.6 (VOUT), R19.2, R24.2
ADC_SCK: IC4.13 (SCK), IC4.18 (SCK); also elsewhere on the board
AGND: C10.1, C12.2, C14.1, C17.1, C18.1, C19.1, C20.1, C22.1, C23.2, C24.1, C25.1, C28.1, C29.2, C33.1, C34.1, D2.A, D4.A, IC4.5 (GND), IC4.10 (GND), IC5.4 (GND), R20.1, R22.1; also elsewhere on the board
AVDD: IC3.3 (V+), IC7.3 (V+); also elsewhere on the board
AVSS: IC3.6 (V-), IC7.6 (V-); also elsewhere on the board
GND: C13.1, C21.1; also elsewhere on the board
unnamed: C12.1, IC4.9 (IN-), R12.2
unnamed: C17.2, IC4.8 (IN+), R16.2
unnamed: C31.1, IC7.4 (OUT+), R27.1, R28.1
unnamed: IC7.5 (OUT-), R30.1
unnamed: C29.1, IC4.4 (IN-), R27.2
unnamed: C33.2, IC4.3 (IN+), R30.2
unnamed: C16.1, IC3.4 (OUT+), R12.1, R13.1
unnamed: IC3.5 (OUT-), R16.1
unnamed: C24.2, IC5.5 (TRIM)
unnamed: IC5.7 (COMP), R25.2
unnamed: C26.1, R25.1
unnamed: C31.2, IC7.1 (FB), R28.2, R29.1
unnamed: C16.2, IC3.1 (FB), R13.2, R14.1
VIDEO_0: D4.C, R29.2; also elsewhere on the board
VIDEO_1: D2.C, R14.2; also elsewhere on the board

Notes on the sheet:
ADC

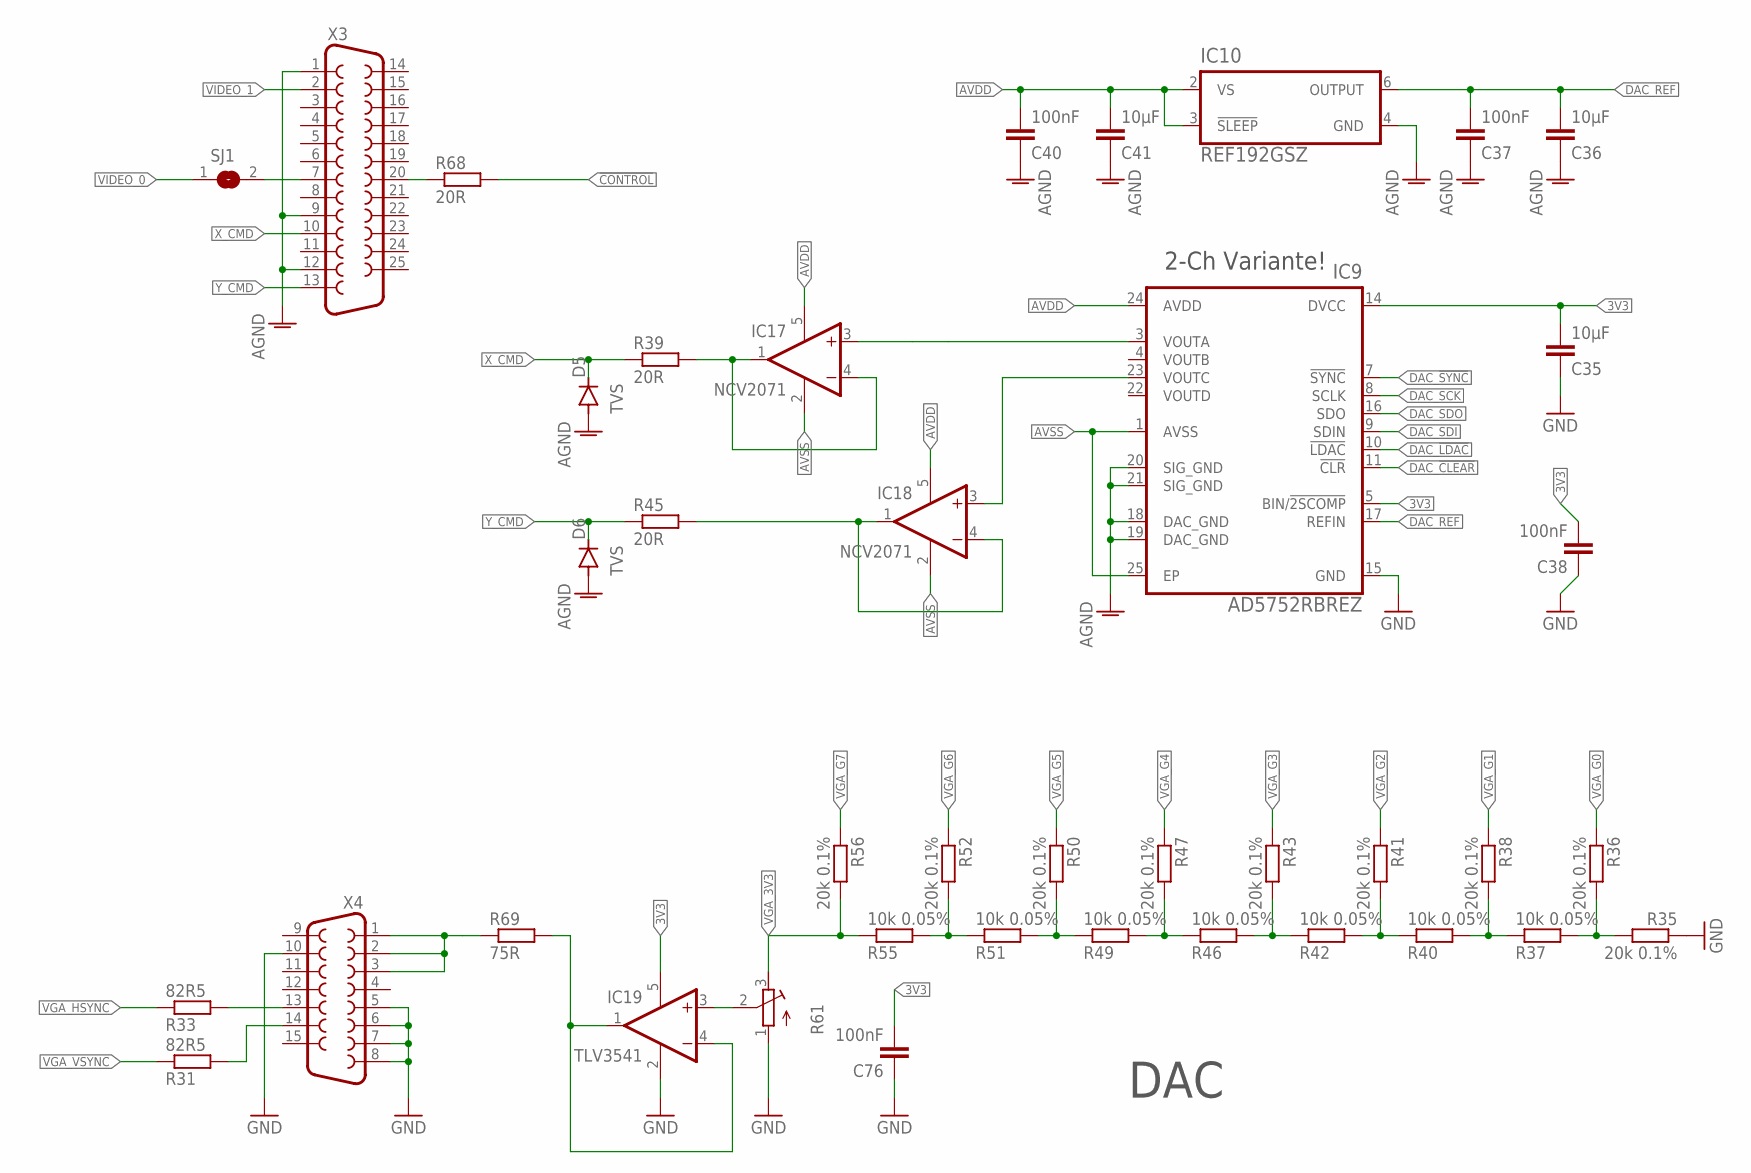
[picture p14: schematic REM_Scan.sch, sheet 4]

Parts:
C35, C36, C41: 10µF; C0603; FARNELL 2497051
C37, C38, C40, C76: 100nF; C0603
D5, D6: TVS; SOD123; DIGIKEY 641-1986-1-ND
IC9: AD5752RBREZ; SOP65P640X120-25N; MPN AD5752RBREZ; FARNELL 1786049
IC10: REF192GSZ; SOIC127P600X175-8N
IC17, IC18: NCV2071; SOT23-5; DIGIKEY NCV20071SN2T1GOSCT-ND
IC19: TLV3541; SOT23-5; DIGIKEY NCV20071SN2T1GOSCT-ND
R31, R33: 82R5; R0603
R35, R36, R38, R41, R43, R47, R50, R52, R56: 20k 0.1%; R0603; FARNELL 1717605
R37, R40, R42, R46, R49, R51, R55: 10k 0.05%; R0603; FARNELL 1688472
R39, R45, R68: 20R; R0603; FARNELL 9330763
R61: R-TRIMM3296W; RTRIM3296W
R69: 75R; R0603; FARNELL 9330763
SJ1: SJ
X3: F25HP
X4: F15HDH; HDF15H

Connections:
3V3: C35.2, C38.2, C76.2, IC9.5 (BIN/!2SCOMP), IC9.14 (DVCC), IC19.5 (V+); also elsewhere on the board
!CONTROL: R68.2; also elsewhere on the board
AGND: C36.1, C37.1, C40.1, C41.1, D5.A, D6.A, IC9.18 (DAC_GND), IC9.19 (DAC_GND), IC9.20 (SIG_GND), IC9.21 (SIG_GND), IC10.4 (GND), X3.1, X3.9, X3.12; also elsewhere on the board
AVDD: C40.2, C41.2, IC9.24 (AVDD), IC10.2 (VS), IC10.3 (!SLEEP), IC17.5 (V+), IC18.5 (V+); also elsewhere on the board
AVSS: IC9.1 (AVSS), IC9.25 (EP), IC17.2 (V-), IC18.2 (V-); also elsewhere on the board
DAC_!CLEAR: IC9.11 (!CLR); also elsewhere on the board
DAC_!LDAC: IC9.10 (!LDAC); also elsewhere on the board
DAC_!SYNC: IC9.7 (!SYNC); also elsewhere on the board
DAC_REF: C36.2, C37.2, IC9.17 (REFIN), IC10.6 (OUTPUT)
DAC_SCK: IC9.8 (SCLK); also elsewhere on the board
DAC_SDI: IC9.9 (SDIN); also elsewhere on the board
DAC_SDO: IC9.16 (SDO); also elsewhere on the board
GND: C35.1, C38.1, C76.1, IC9.15 (GND), IC19.2 (V-), R35.1, R61.1 (A), X4.5, X4.6, X4.7, X4.8, X4.10; also elsewhere on the board
unnamed: SJ1.2, X3.7
unnamed: R31.2, X4.14
unnamed: R69.1, X4.1, X4.2, X4.3
unnamed: R33.2, X4.13
unnamed: R35.2, R36.2, R37.2
unnamed: R37.1, R38.2, R40.2
unnamed: R40.1, R41.2, R42.2
unnamed: R42.1, R43.2, R46.2
unnamed: R46.1, R47.2, R49.2
unnamed: R49.1, R50.2, R51.2
unnamed: R51.1, R52.2, R55.2
unnamed: IC19.1 (OUT), IC19.4 (-IN), R69.2
unnamed: IC17.1 (OUT), IC17.4 (-IN), R39.2
unnamed: IC9.3 (VOUTA), IC17.3 (+IN)
unnamed: IC18.1 (OUT), IC18.4 (-IN), R45.2
unnamed: IC9.23 (VOUTC), IC18.3 (+IN)
unnamed: R68.1, X3.20
unnamed: IC19.3 (+IN), R61.2 (S)
VGA_3V3: R55.1, R56.2, R61.3 (E)
VGA_G0: R36.1; also elsewhere on the board
VGA_G1: R38.1; also elsewhere on the board
VGA_G2: R41.1; also elsewhere on the board
VGA_G3: R43.1; also elsewhere on the board
VGA_G4: R47.1; also elsewhere on the board
VGA_G5: R50.1; also elsewhere on the board
VGA_G6: R52.1; also elsewhere on the board
VGA_G7: R56.1; also elsewhere on the board
VGA_HSYNC: R33.1; also elsewhere on the board
VGA_VSYNC: R31.1; also elsewhere on the board
VIDEO_0: SJ1.1; also elsewhere on the board
VIDEO_1: X3.2; also elsewhere on the board
X_CMD: D5.C, R39.1, X3.10
Y_CMD: D6.C, R45.1, X3.13

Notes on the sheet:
DAC
2-Ch Variante!

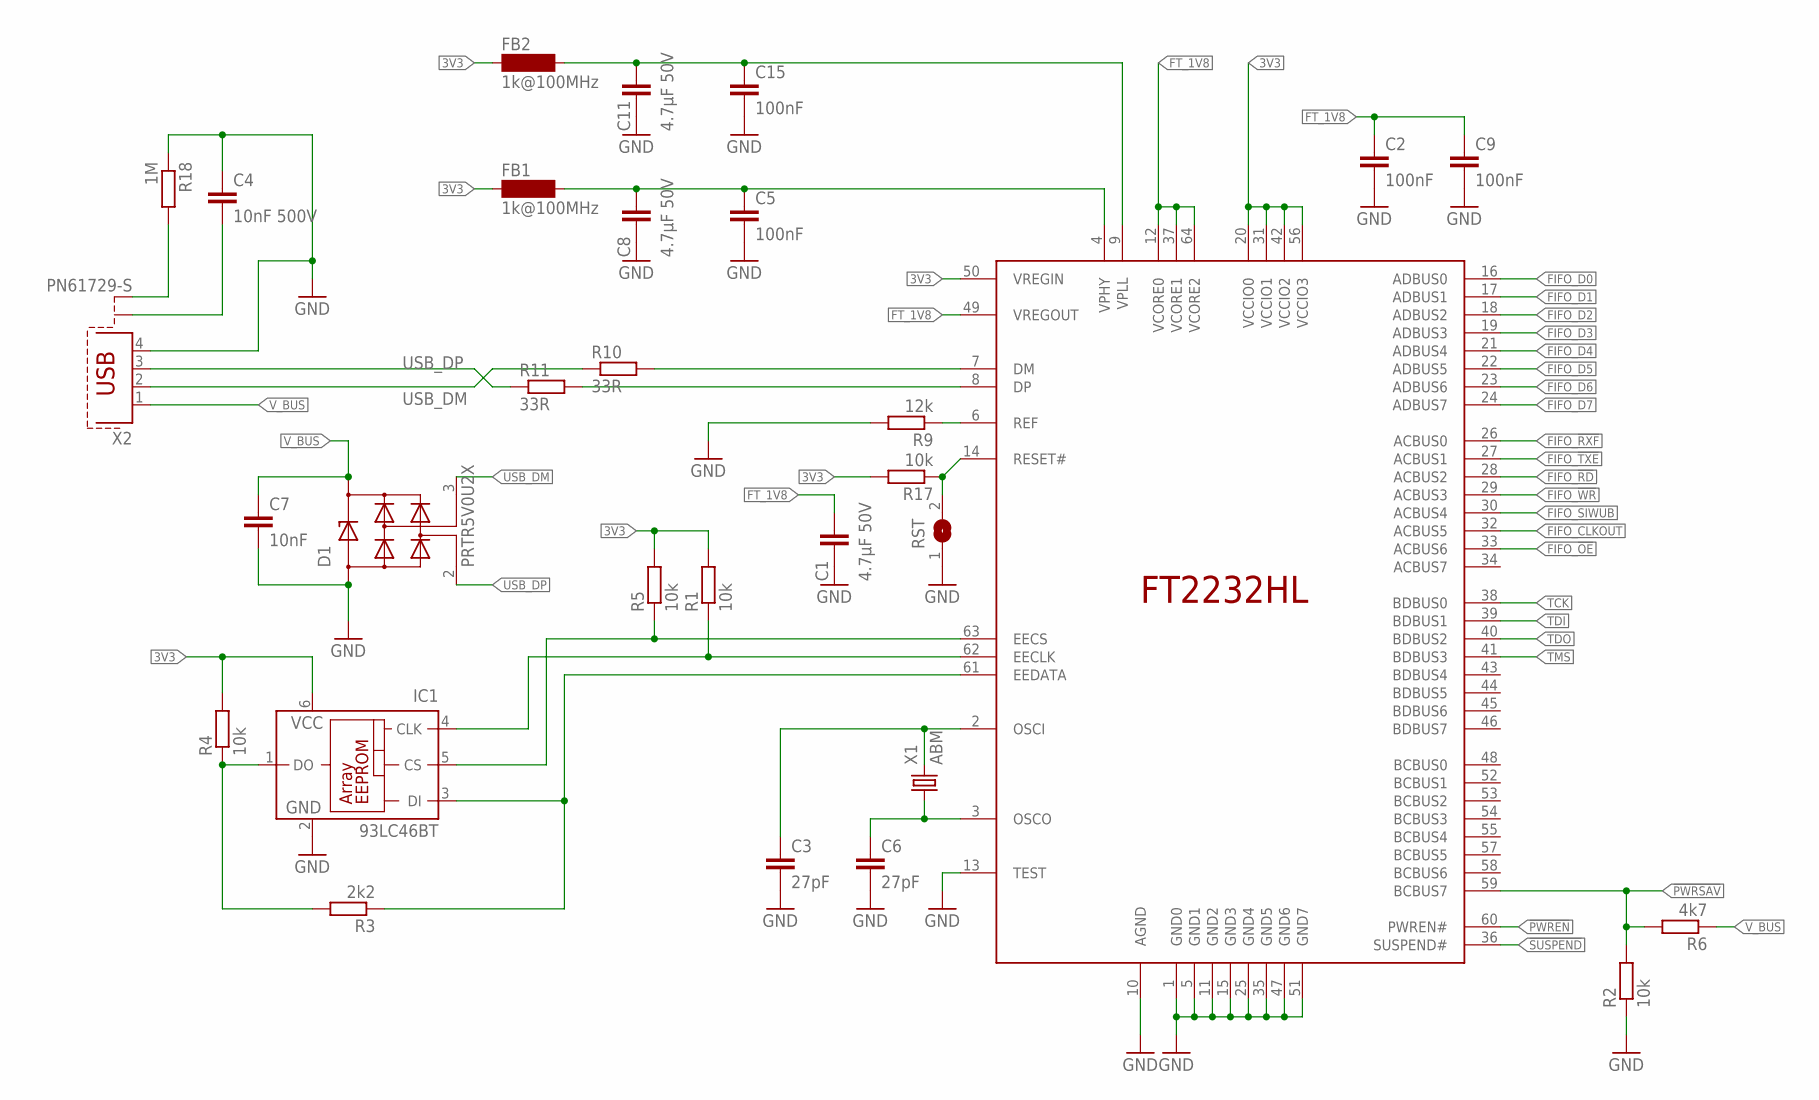
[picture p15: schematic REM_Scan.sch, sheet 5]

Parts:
C1, C8, C11: 4.7µF 50V; C0805
C2, C5, C9, C15: 100nF; C0603
C3, C6: 27pF; C0603
C4: 10nF 500V; C0805
C7: 10nF; C0603
D1: PRTR5V0U2X; SOT143; FARNELL 1524157
FB1, FB2: 1k@100MHz; SM-1206; FARNELL 1635759
IC1: 93LC46BT; SOT23-6; FARNELL 1556164
IC2: FT2232HL; LQFP64; FARNELL 1697461
R1, R2, R4, R5, R17: 10k; R0603
R3: 2k2; R0603
R6: 4k7; R0603
R9: 12k; R0603
R10, R11: 33R; R0603
R18: 1M; R0603
RST: SJS
X1: ABM; ASE; FARNELL 2308707
X2: PN61729-S

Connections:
3V3: FB1.1, FB2.1, IC1.6 (VCC), IC2.20 (VCCIO0), IC2.31 (VCCIO1), IC2.42 (VCCIO2), IC2.50 (VREGIN), IC2.56 (VCCIO3), R1.2, R4.2, R5.2, R17.2; also elsewhere on the board
!PWREN: IC2.60 (PWREN#); also elsewhere on the board
!PWRSAV: IC2.59 (BCBUS7), R2.2, R6.2
!SUSPEND: IC2.36 (SUSPEND#); also elsewhere on the board
FIFO_!OE: IC2.33 (ACBUS6); also elsewhere on the board
FIFO_!RD: IC2.28 (ACBUS2); also elsewhere on the board
FIFO_!RXF: IC2.26 (ACBUS0); also elsewhere on the board
FIFO_!TXE: IC2.27 (ACBUS1); also elsewhere on the board
FIFO_!WR: IC2.29 (ACBUS3); also elsewhere on the board
FIFO_CLKOUT: IC2.32 (ACBUS5); also elsewhere on the board
FIFO_D0: IC2.16 (ADBUS0); also elsewhere on the board
FIFO_D1: IC2.17 (ADBUS1); also elsewhere on the board
FIFO_D2: IC2.18 (ADBUS2); also elsewhere on the board
FIFO_D3: IC2.19 (ADBUS3); also elsewhere on the board
FIFO_D4: IC2.21 (ADBUS4); also elsewhere on the board
FIFO_D5: IC2.22 (ADBUS5); also elsewhere on the board
FIFO_D6: IC2.23 (ADBUS6); also elsewhere on the board
FIFO_D7: IC2.24 (ADBUS7); also elsewhere on the board
FIFO_SIWUB: IC2.30 (ACBUS4); also elsewhere on the board
FT_1V8: C1.1, C2.1, C9.1, IC2.12 (VCORE0), IC2.37 (VCORE1), IC2.49 (VREGOUT), IC2.64 (VCORE2)
GND: C1.2, C2.2, C3.2, C4.1, C5.2, C6.2, C7.2, C8.2, C9.2, C11.2, C15.2, D1.1 (GND), IC1.2 (GND), IC2.1 (GND0), IC2.5 (GND1), IC2.10 (AGND), IC2.11 (GND2), IC2.13 (TEST), IC2.15 (GND3), IC2.25 (GND4), IC2.35 (GND5), IC2.47 (GND6), IC2.51 (GND7), R2.1, R9.2, R18.1, RST.1, X1.2 (GND), X1.4 (GND), X2.4; also elsewhere on the board
unnamed: R18.2, X2.S2
unnamed: C4.2, X2.S1
unnamed: IC2.7 (DM), R10.2
unnamed: IC2.8 (DP), R11.2
unnamed: IC1.5 (CS), IC2.63 (EECS), R5.1
unnamed: IC1.4 (CLK), IC2.62 (EECLK), R1.1
unnamed: IC1.3 (DI), IC2.61 (EEDATA), R3.1
unnamed: C3.1, IC2.2 (OSCI), X1.3 (2)
unnamed: C6.1, IC2.3 (OSCO), X1.1
unnamed: IC1.1 (DO), R3.2, R4.1
unnamed: IC2.14 (RESET#), R17.1, RST.2
unnamed: IC2.6 (REF), R9.1
TCK: IC2.38 (BDBUS0); also elsewhere on the board
TDI: IC2.39 (BDBUS1); also elsewhere on the board
TDO: IC2.40 (BDBUS2); also elsewhere on the board
TMS: IC2.41 (BDBUS3); also elsewhere on the board
USB_DM: D1.3 (IO2), R10.1, X2.2
USB_DP: D1.2 (IO1), R11.1, X2.3
VPHY: C5.1, C8.1, FB1.2, IC2.4 (VPHY)
VPLL: C11.1, C15.1, FB2.2, IC2.9 (VPLL)
V_BUS: C7.1, D1.4 (VCC), R6.1, X2.1; also elsewhere on the board

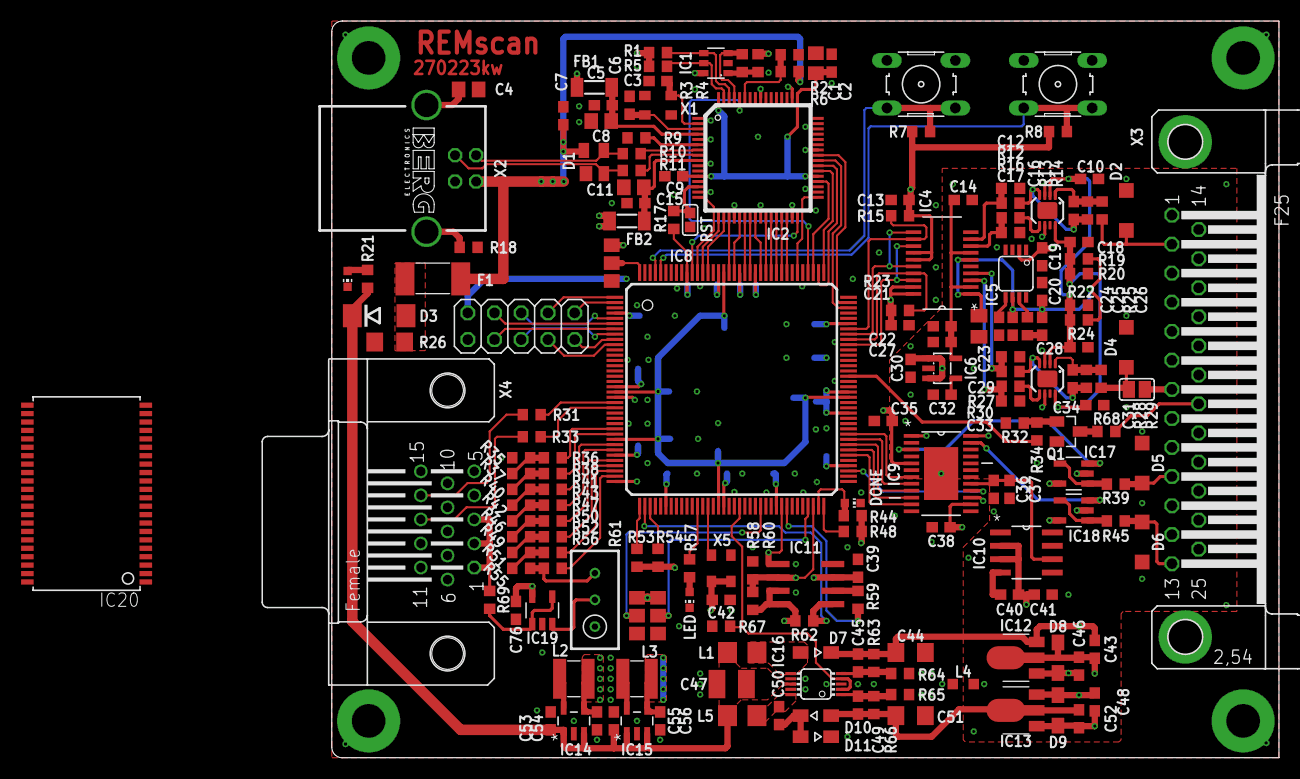
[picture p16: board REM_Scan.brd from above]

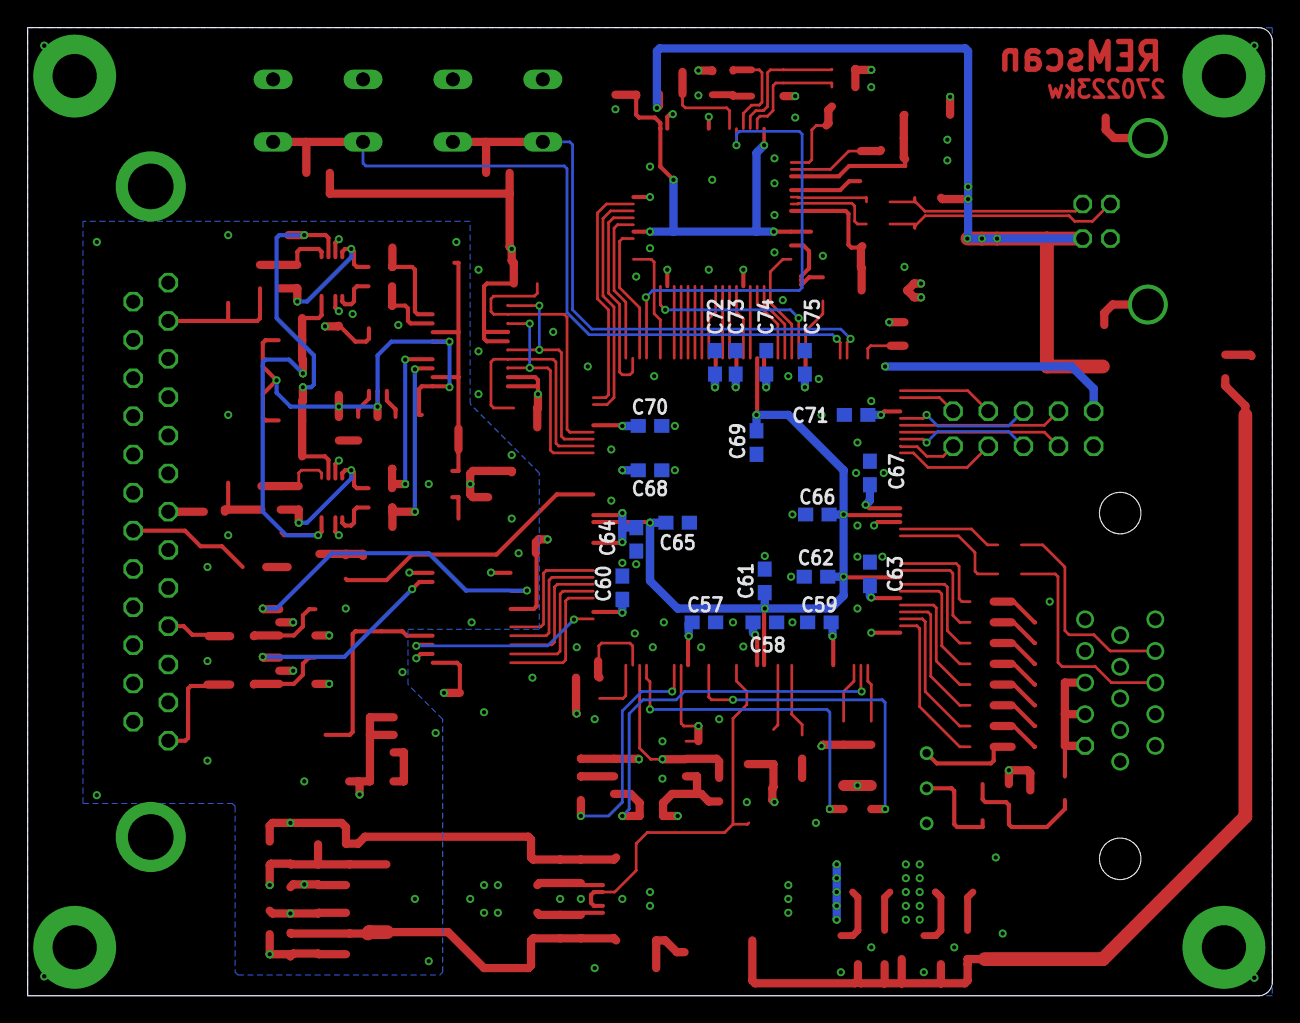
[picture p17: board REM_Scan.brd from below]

Board: 4 copper layers, 90.0 x 70.0 mm, 201 parts (19 on the bottom side), 150 nets.
